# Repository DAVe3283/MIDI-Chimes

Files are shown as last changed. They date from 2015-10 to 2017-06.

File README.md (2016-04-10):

# MIDI-Chimes
Software &amp; notes from retrofitting some old chimes to MIDI control

Eventually, this will contain schematics, PCB layouts, data sheets, and source
code to make everything work. I will add things as I get to them.

## Project Details

TODO: writeup project details

## Firmware

The project uses several Teensy 3.2 microcontrollers. There is a master, which
handles MIDI and the user interface. The rest are slaves, which run 10 chimes
each.

The master and slaves communicate over I2C. The master talks to a touch screen
LCD over SPI.

### Libraries

I am using the following libraries:

* [i2c_t3][] - A superior I2C library that runs quite fast on the Teensy3.
* [ILI9341_t3][] - An optimized ILI9343 SPI LCD driver library for the Teensy3.
* [ILI9341_fonts][] - Additional fonts for ILI9341_t3.
* [Adafruit_STMPE610][] - STMPE610 SPI touch screen controller library.
* [Adafruit_FT6206][] - FT6206 I2C touch screen controller library.
* [SdFat][] - SD Card + FAT file system library.
* [IniFile][] - Arduino library to parse INI files.

Some minor changes are needed to make the libraries work together for this
project.

#### Adafruit_STMPE610

The line `#include <Wire.h>` needs changed to `#include <i2c_t3.h>` or it
conflicts with the i2c_t3 library.

#### SdFat

To work right, the SdFat library needs the following settings in SdFatConfig.h:

`#define SD_SPI_CONFIGURATION 1`

This uses the Arduino SPI.h library, which is really an optimized one for the
Teensy 3.1.

`#define ENABLE_SPI_TRANSACTION 1`

This enables SPI transactions, which makes using multiple devices on the SPI bus
much nicer.

I had some issues with SdFat-beta, but I might go back and make that work,
because it does some cool stuff.

#### IniFile

In IniFile.h, `#include <SD.h>` needs changed to `#include <SdFat.h>`.

Immediately below the includes, add the following so the inline code works with
this program:

```c++
extern SdFat sd;
#define SD sd
```

## Schematics

See the "PCB & Schematic" directory, and the [PCB.md](Notes/PCB.md) file.

## License

Content in each folder may be licensed differently. Overall, I strive to use the
Unlicense, but some portions may use external libraries preventing that. Those
portions will be licensed as necessary. Data sheets and the like are provided
for reference only, and are subject to all licenses/copyright specified within.

[Adafruit_FT6206]: https://github.com/adafruit/Adafruit_FT6206_Library
[Adafruit_STMPE610]: https://github.com/adafruit/Adafruit_STMPE610
[i2c_t3]: https://github.com/nox771/i2c_t3
[ILI9341_fonts]: https://github.com/PaulStoffregen/ILI9341_fonts
[ILI9341_t3]: https://github.com/PaulStoffregen/ILI9341_t3
[SdFat]: https://github.com/greiman/SdFat
[IniFile]: https://github.com/stevemarple/IniFile

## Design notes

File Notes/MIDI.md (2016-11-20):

# MIDI Messages

## Channels

The MIDI standard has 16 channels, theoretically for up to 16 different devices.
However, multiple devices can share a channel, so... ??

## Programs

MIDI programs are basically instruments. A Program Change message is sent to a
channel, and that channel is now supposed to be that instrument. Or that is what
seems expected in the real world.

## MIDI Keyboard Specific

I bought a Monoprice [606607][] 49-Key MIDI keyboard to use with the chimes.
I plan to take advantage of some of its features.

The keyboard uses rotary encoder A1 to set the program (instrument) and encoder
B2 to set the channel volume (Control Change for controler 0x07), 0-127.

### Analog Slider

There is an analog slider that I could use as an easier/quicker way to set the
volume on the chimes. I should make this an option in the GUI.

In the default config, it sends CC 147 (Master Volume), 0-127.

| Position | Raw Value  | Message |
| ---: | ---: | --- |
| 0% | 0 (0x00) | `F0 7F 7F 04 01 00 00 F7` |
| 25% |  32 (0x20) | `F0 7F 7F 04 01 00 20 F7` |
| 50% |  64 (0x40) | `F0 7F 7F 04 01 00 40 F7` |
| 75% |  96 (0x60) | `F0 7F 7F 04 01 00 60 F7` |
| 100% | 127 (0x7F) | `F0 7F 7F 04 01 00 7F F7` |

I think it might be good to honor this as well as the channel volume.

### Modulation Wheel

This is probably present on more keyboards than an analog slider, so I might
consider allowing this to control volume as well (as an option in the GUI).

The message is the standard modulation wheel (Control Change for controller
0x01), 0-127.

This should probably be off by default, because this would not be any kind of
expected behavior, and certainly wouldn't be intuitive.

# Our Behavior

Officially, we should make the user select a channel (1-16), and only listen to
that channel. Additionally, we would only play notes on that channel if a
program of 14 (0x0E, tubular bells) was selected.

However, we can't control/predict how MIDI files will be written. So the
official behavior might end up not playing certain songs at all, or requiring
the user to select the right channel.

So, we can do a couple things:

* Follow the spec
* Listen on all channels for just Tubular Bells
* Listen on one channel for all programs

The options above could be selected as a mode by the user.

## Follow the spec

This would behave as expected in a production / commercial environment. But I
really think this would cause a lot of MIDI files not to play back.

## Listen on all channels for just Tubular Bells

If we add an "All" to the channel selection, this could be a good option. It
follows the spec, unless the user says "ALL". And in that case, it is pretty
clear what will happen, IMO.

I would lean toward this option.

### Tech Details

I would probably need an array of bools for all 16 channels to track if they are
currently configured for Tubular Bells. Because some wanker might use multiple
channels of bells for some reason.

## Listen on one channel for all programs

Upside: This would cause MIDI files not designed for chimes to play.

Downside: This would cause MIDI files not designed for chimes to play.

This is probably a bad enough option it isn't worth implementing.

## Decision

I will follow the spec, but implement an "ALL" channel that listens for tubular
bells on all channels.

Internally, both the Teensy USB MIDI library and my library use channel 0 to
indicate ALL/ANY. So I have to add 1 to the channel as it comes in over the MIDI
port to match USB MIDI behavior.

# MIDI OUT / THRU

I will be using a single combined OUT/THRU port, with behavior selected in
software.

Officially, the MIDI OUT port is for data generated by the chimes. But chimes
don't really generate data.

I am thinking there should be a setting to control if MIDI files played by the
chimes send data to the MIDI OUT port or not.

I guess, fundamentally, I don't know what I want to do with this port yet.

[606607]:http://www.monoprice.com/product?p_id=606607

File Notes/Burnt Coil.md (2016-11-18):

# Burnt Coil Rebuild

One of the coils for the chime was overheated and damaged. It measured
approximately half the impedance of the normal coils, and was visibly burnt.

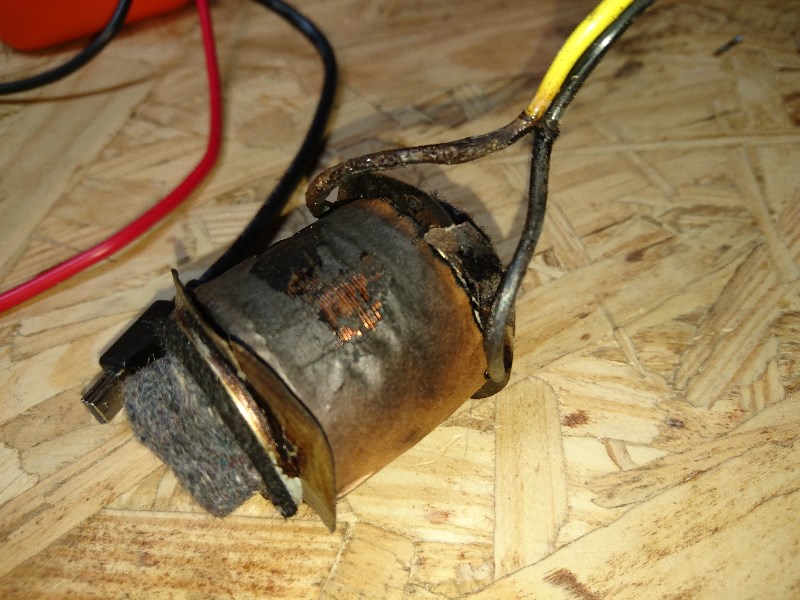
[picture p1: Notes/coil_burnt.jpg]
Picture of the burnt coil


The high current through this coil was causing problems for the transistor I
selected for the driver board, so I decided to re-wind the coil.

## Original Winding

To start, I removed the existing windings by hand. The first 5 layers were all
50 turns per layer, so I stopped counting turns and started counting layers. I
still periodically verified the layers were 50 turns, and they were throughout.

### Turns

Final result: **950 turns** (50 turns per layer, 19 layers)

It is technically possible I mis-counted layers, and it is actually 1000 turns
(20 layers), but I was careful, so I think it actually is 950 turns.

### Wire

Wire is 0.018" ± 0.0005" (indicated) based on my measurements with a cheap
Harbor Freight digital caliper. That puts it at a nominal 24 or 25 gauge.

Total wire length removed is approximately 250' (measured with a tape measure).

Calculating the expected resistance for 250' of 25 AWG wire yields 8.09 ohms,
which matches the other coils (8.0 ohms on my meter).

I think it is safe to say the coil uses **25 AWG** magnet wire.

## Core

The coil core was then exposed, and was measured.

The center section was not actually round, but narrowed in the center slightly.
The outer edges are 14.0 mm in diameter, and the center is 13.5 mm in diameter.

The winding section is 31 mm long, though the original winding didn't take the
whole area, but was centered on it. I was unable to get a good measurement of
the original winding width, but it appeared to be about 22-25 mm wide.

## New Winding

I ordered 25 AWG magnet wire, and used my lathe to re-wind the burnt coil with
new wire. I didn't have the proper paper for separating layers, so I used
standard multi-purpose copy paper soaked with insulating varnish. Not ideal, but
it worked.

I ended up winding the coil with more turns per layer and less layers than the
original. The rebuilt coil measures 7.2 ohms, so a little low, but way better
than the sub-4 ohm resistance from before.

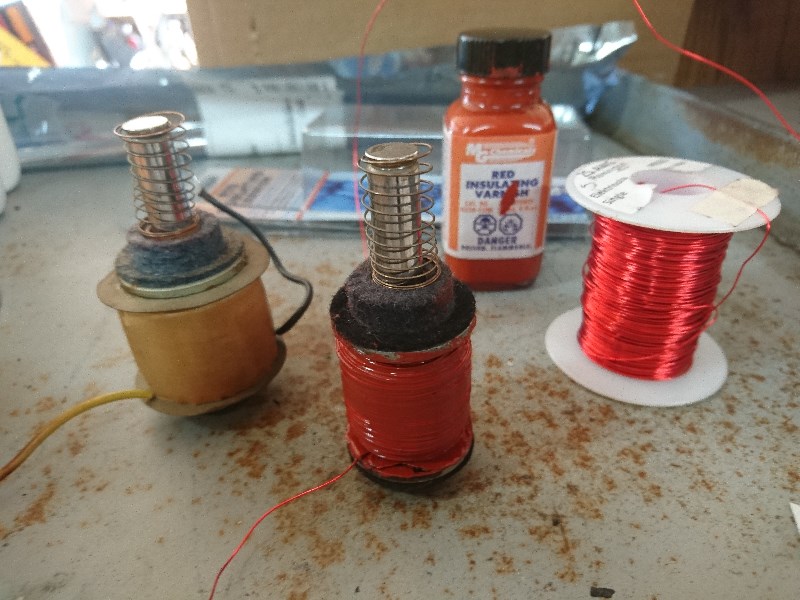
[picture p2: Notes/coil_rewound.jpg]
Picture of the rewound coil next to an original coil


The new coil tests out fine using a bench supply, and should be easy to
calibrate with the firmware to match the original coils.

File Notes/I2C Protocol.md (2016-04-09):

# I2C Protocol

This documents the protocol I am using for the I2C bus.

# Write (Master to Slave)

While I could get clever and allow multiple channels to be turned on and off per
message, there is no need for this. The I2C bus is substantially faster than the
incoming MIDI messages (per the spec, at least), so I can be lazy and just
handle one channel at a time.

Even more lazy, since the strike time for the chime is predetermined, and there
are no dampers on this setup, I don't even have to support a "note off" message
at all! So I don't.

## Note On Message

| Offset | Size | Type | Meaning |
|---|---|---|---|
| 0 | 1 | uint8_t  | Channel |
| 1 | 2 | uint16_t | PWM Duty Cycle |

### Channel

The channel (local to the current slave) is which activated/struck.

### PWM Duty Cycle

This is a 12-bit value (sent as 16-bits). Any value greater than 12 bits is
treated as 100% by the Teensy libraries.

I believe this is sent as little-endian, but it doesn't matter since both master
and slave use the same processor.

# Read (Master request from Slave)

When the master requests a read from the slave, the slave writes the following
packet back to the master.

## Status Packet

| Offset | Size | Type | Meaning |
| -----: | ---: | --- | --- |
| 0 | 1 | uint8_t  | Message Version |
| 1 | 1 | uint8_t  | PWM Bits |
| 2 | 1 | uint8_t  | Physical Channels (n) |
| 3 | 1 | uint8_t  | Connected Channels |
| 4 | 2 | uint16_t | Power Supply Voltage  |
| 6 |  n*1 | uint8_t  | Channel State |
| 6+n |  n*1 | uint8_t  | Strikes Remaining |
| 6+2n |  n*2 | uint16_t | Channel Voltage |

### Message Version

Currently set to 0, but this allows me to change things in the future in a
backwards-compatible way.

### PWM Bits

How many bits resolution the PWM is using on this slave. Currently 12, but could
change. The master should ensure all PWM duty cycle values are in this range.

### Physical Channels

How many physical channels this board has. Currently 10.

The message is scaled to the number of channels used.

### Connected Channels

How many of the physical channels appear to be connected to chime coils.

This is there because I have 25 chimes, so the last slave board will only have
5 connected channels.

### Power Supply Voltage

The slave board's best guess at power supply voltage setpoint, measured during
startup.

### Channel State

This is an enum value that indicates the current state of each channel.
Currently:

| Value | Meaning |
| ----- | --- |
| 0 | Working normally |
| 1 | Disconnected (no coil detected) |
| 2 | Transistor failed to short circuit |
| 3 | Transistor failed to open circuit  |

The channel disconnected status is so the master can verify the expected number
(and location) of coils are connected. If something isn't right, it should
display a message to the user, and ask them to verify the connections.

If a channel is failed to short circuit, the main power supply should be turned
off to prevent damage to the coil attached to that channel. The slave will
attempt to do this on its own, but the master should turn off the main supply
itself, just to be safe. The master should display a message to the user, so
they know what happened.

If a channel is failed to open circuit, it is safe to keep using the channel and
to leave the master supply on, but that channel may not work. The master should
display a message to the user so they know what happened.

### Strikes Remaining

A counter of how many more times we can strike this chime before the coil is
considered overheated. If this value is 0, the channel is overheated and will
ignore strike commands to protect the coil.

As time passes (and the coil cools), this value will increase, allowing the
channel to be used again.

This is purely informational, as the slave manages the thermals. However, it
might be fun to have a live display of the strikes remaining values.

### Channel Voltage

This is the last measured voltage of the given channel with the transistor off
(not striking the chime). It is measured once at startup, and again every time
a chime is finished striking.

This is purely informational, but might be fun to have a live display on the
master of all the channel voltages.

# Startup Process

The startup process is a bit more complex, and might stretch the spec a bit...

The slaves power up and start listening on the I2C General Call Address (0x00).
All slaves listen simultaneously, since the bus is shared.

## Commands

The master uses 2 byte messages during startup. The 1st byte is a command, and
the 2nd byte is the value. The meaning of the value is described below.

| Command | Value |
|---|---|
| 0x00 Set Address | Address to use if/when ADDR_LATCH goes high |
| 0x01 Set ADDR_LATCH | Set the output ADDR_LATCH pin to this value |
| 0x02 Startup Complete | Value is currently ignored |

### 0x00 Set Address

When this command is received, all slaves prepare to switch to this address.
But only when ADDR_LATCH_IN goes high does it take effect, so only one slave
will actually get assigned to the address.

### 0x01 Set ADDR_LATCH

Since only the first slave is connected to the master directly, the master has
to request downstream slaves set their ADDR_LATCH_OUT, so that the next slave in
line latches the last address sent.

### 0x02 Startup Compete

When the master is done with a slave, it sends this, telling the slave to begin
normal operation. The value sent with this command is currently ignored.

## Fun Extras

It would be interesting to test and see if the R_BE (Base-Emitter resistance)
across the transistors is fairly consistent. From the data sheet, it looks to be
0.45-0.56 ohms depending on current flow. My testing shows it vary from 120 ohms
at 5mA then dropping quickly under 1 ohm by 1 A, and down to ~0.45 ohms at ~2.5
amps.

Perhaps instead, I could connect some various resistive (or inductive) loads and
just make a calibration curve of feedback voltage (at 100% PWM) vs. current, if
the transistors are consistent enough. Might be fun to have each coil's current
consumption (and resistance, since we have the power supply voltage) show up in
a diagnostics screen on the master.

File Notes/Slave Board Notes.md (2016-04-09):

Notes about the slave board.

Voltage measured with transistor on 100%:

| Current (mA) | Voltage |  R_BE |
| ---: | --- | ----: |
| 5 | 0.6 | 120.0 |
| 1000 | 0.8 | 0.8 |
| 2000 | 0.9 |  0.45 |
| Actual Coils | 1.1 | ~0.44 |

So any voltage over 0.5V at boot means something is connected.
I should probably consider anything under 1.5V (and < 50% ps_setpoint) shorted at startup.

Or, since the chimes will draw ~2A, simply subtract 0.9V from the measured
voltage, and use that for the percentage calculations to verify operation?

Perhaps some testing with the real chimes is in order...

Measured values from my chimes.
Ideal values calced with
    ideal_voltage = ps_setpoint - ((ps_setpoint - transistor_Vce_drop) * set_dc[channel])
    ps_setpoint = 19.13
    transistor_Vce_drop = 1.1

| PWM DC | Measured | Ideal | Error |
| -----: | --- | ----- | ----: |
| 0% | 19.13 | 19.13 |  0.0% |
| 10% | 17.76 | 17.33 | -2.3% |
| 20% | | 15.52 | |
| 30% | 14.07 | 13.72 | -1.8% |
| 40% | 12.18 | 11.92 | -1.4% |
| 50% | 10.31 | 10.12 | -1.0% |
| 60% | 8.38 |  8.31 | -0.4% |
| 70% | 6.51 |  6.51 |  0.0% |
| 80% | 4.61 |  4.71 |  0.5% |
| 90% | 2.73 |  2.90 |  0.9% |
| 100% | 1.10 | 1.1 |  0.0% |

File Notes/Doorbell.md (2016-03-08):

I want the chimes to work as a doorbell as well as MIDI chimes. Why? Why not?

To make this happen, I bought a doorbell (GE 19247) for $14 or so.

# GE 19247

This sucker is surprisingly well designed. The PCB appears to be one layer
(though it has screen-printing on both sides), with the CPU inserted vertically
on a card. Impressively well laid out, IMO.

Furthermore, it appears the speaker output is isolated from ground. This is the
correct way to do things (I am impressed, especially at this price point), but
sadly, that means simply snooping a speaker pin won't work.

## EEPROM

There is a FM24C02C 256x8 bit EEPROM attached to the CPU. When the doorbell
button is pressed, there is some I/O traffic to the EEPROM. Here is one exchange
I captured.

| Address |  R/W  | Value |
|---|---|---|
| 0x13 | Read  | 0x0A  |
| 0x01 | Read  | 0x26  |
| 0x02 | Read  | 0x87  |
| 0x03 | Read  | 0x90  |
| 0x14 | Read  | 0x0A  |
| 0x04 | Read  | 0x79  |
| 0x05 | Read  | 0xA5  |
| 0x06 | Read  | 0xD0  |
| 0x0A | Read  | 0x01  |
| 0x0A | Write | 0x01  |

I have no idea what it is doing with that data (or why it re-writes 0x0A from 1
to 1), but it doesn't matter for what we are doing.

## A trick!

Since we can't read the speaker output (floating ground), we need _some_ way to
tell the doorbell button was pressed. Well, we can watch SCL (or SDA) for a
high-to-low transition. That indicates the start of some I2C traffic, and
therefore, a button press!

## Measurements

The SCL and SDA lines appear to be pulled up to 2.7V, and the CPU itself runs
on 2.9V. 2.7V should be sufficiently high to count as logic high on the Teensy,
which runs at 3.3V.

The I2C bus is clocked at approximately 5.6 kHz, with occasional long pauses
mid-transaction. Given how slow it is, I doubt the wire running to the Teensy
will cause any bus corruption.

# TODO

I need to solder a wire to the SCL line, and hook it to the Teensy to verify I
can reliably detect button presses. I should also leave it running for a long
time period to count bus events, and make sure there is no random idle bus
traffic that would cause the doorbell to go off randomly.

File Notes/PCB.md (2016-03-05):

# Data Connector Pinout

This is the connector between the master and slave devices.

| Pin |  Description  |
| --- | --- |
| 1 | Ground |
| 2 | +5V_SB |
| 3 | I2C SCL |
| 4 | I2C SDA |
| 5 | Address Latch |
| 6 | PS_EN |

+5V_SB is 5V standby power from the PSU.
PS_EN is the power supply enable line.
Address latch is used to auto-assign I2C addresses on startup (future use).

If I did this right, no magic smoke should escape if (when) someone plugs this
connector in backwards. Off-by-one... not so much.

# Transistor Feedback Voltage

I am using a 160k / 10k resistor divider, with a 1 uF capacitor in parallel with
the 10k resistor. Using the Teensy3's internal 1.2V precision reference, I can
read a transistor voltage of 0 to 20.4 volts. The capacitor filters out the PWM
frequency, letting me be extremely lazy with my firmware when checking how
things are working.

# Master

## Power Supply Connector

This is the pinout of the connector on the high voltage power supply.

Note how the power supply datasheet counts terminal numbers! It might not be
what you expect. For consistency, I use the same numbering as the datasheet.

| Pin | Description |
|-----|---|
| 1 | RC+ |
| 2 | RC- |
| 3 | AUX (5V_SB) |
| 4 | AUX_GND |
| 5 | +S |
| 6 | -S |

### RC

The RC+ and RC- pins are for Remote Control of the power supply. Shorting RC+ to
RC- will turn off the power supply. It also appears that RC- is internally tied
to AUX_GND, but I probably should explicitly do that on the PCB to be safe.

### AUX

This is a 5V standby power supply, limited to 300 mA. I think we come in under
that, but it bears testing. If not, I might have to get creative...

### +/-S

This is a sense line to compensate for voltage droop at the load. We don't care,
so these should be left unconnected. Probably best not to put wires in the
header, so stray EMI doesn't get picked up.

## I2C Bus

I need external pullup resistors on the I2C bus, as the internal Teensy ones
don't work all that well. For high speed, I probably want 1.5k or so.

## Legacy MIDI Ports

I am going to support the legacy DIN MIDI jacks. MIDI uses a current loop and
opto-isolator (optocoupler) to avoid ground loops. I will be using the 6N138.

I think I can use the MAB5SH part in Eagle as the footprint for the MIDI conenctor.
    Yeah, I think we're good. But just in case: http://www.newark.com/hirschmann/mab-5-sh/din-audio-video-connector-socket/dp/61T4646

I need to use a protection diode on the MIDI In port to protect the optocoupler
from exceeding its breakdown voltage (5V max). I could use the diode I use to
absorb flyback from the coils. Massive overkill, but simplifies the BoM. A small
surface mount part might be easier to lay out, though.

### Simple Option

I need some sort of output transistor for the MIDI out/through circuit.
Worst case, a shorted cable could cause a load of up to 23 mA (5 V / 220 ohms)
when pulling MIDI_OUT to ground, but the Teensy can only handle 9 mA per pin.

Plus, a faulty/malicious device could actually put more than 5V on Pin 5. A
transistor with sufficient ratings solves all this.

#### Overkill option

Because this is a chance for me to have too much fun with design and learn some
things, I could isolate the MIDI out as well. I would need an opto-isolator, and
an isolated power supply to provide the 5V for the current loop and to run the
optocoupler.

I will order a REE-0505S from Mouser and see if it works well enough. If not, I
will try a MEV1S0505SC, but this would need a footprint designed for Eagle.
(Actually, I need to verify the generic DC-DC footprint works on the REE...)

If that all works, I could route out an isolation gap in the PCB, and do all the
high-voltage design. Of which I currently know nearly nothing. But once I learn,
I would have a MIDI input/output stage with > 1000V isolation! heh

## Misc

http://www.mouser.com/ProductDetail/Molex/15-91-2140/?qs=sGAEpiMZZMttdt6ek4ZYDGcRuHgvKenX
    This is for the pads on the back of the Teensy.

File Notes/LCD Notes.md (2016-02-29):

Notes about the LCD screen.

# Connection / Pins

The display pins are numbered like an Arduino UNO.

| Circuit | Teensy | Arduino |
| ---  | -----: | ---: |
| LCD Reset | 7 | RESET |
| SPI Touch CS  | 8 | 8 |
| I2C Touch SCL | 19 | A5/SCL  |
| I2C Touch SDA | 18 | A4/SDA  |
| LCD DC | 9 | 9 |
| LCD CS | 10 | 10 |
| SPI MOSI | 11 | 11 |
| SPI MISO | 12 | 12 |
| SPI SCK | 14 | 13 |
| MicorSD CS | 15 | 4 |
| LED Backlight | 3 | 3 |

CS = chip select
DC = data/command select, appears non standard, used for display
I2C: Use the pins on the same side as the SPI bus of the display board. Arduino exposes these pins in two places, and only one pair works.

# Backlight

The backlight intensity can be controlled by PWM-ing the backlight pin to switch
the LEDs on and off.

I tried a 16-bit PWM @ 549 Hz and could see no noticable flicker. I think that
16 bits is serious overkill. Even 8 bits might be overkill.

| PWM % DC | Percieved Brightness |
|---|---|
| 0% (Off) | Can't see anything |
| 1/65535  | Can't see anything |
| 1% | Very dim, almost unusable |
| 5% | Usable in soft indoor light |
| 10% | About 25% full brightness |
| 30% | About 50% |
| 50% | About 75% |
| 90% | About 98% |

If the backlight is turned completely off, you can't see _anything_, even by
shining a flashlight on the screen. For all intents and purposes, the screen is
off. We probably want to avoid this.

For a standby/eco mode (power supply off), something in the 1% - 5% range is
probably good.

For an "unattended" mode (chimes active but no display interaction for some
time), something in the 30-50% rand is probably good.

It would be cool to have it smoothly ramp the brightness up and down as the
chimes transition between various power saving modes. Make the transition quick
enough to not get in the way of user operation, but slow enough to look good.
That probably means in the 100 - 500 ms range to get brighter on interaction.
We could fade out much more slowly (1-5 seconds?) though.

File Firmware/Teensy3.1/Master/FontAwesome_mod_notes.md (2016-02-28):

# FontAwesome_mod

What things are in my custom FontAwesome mod...

## Battery

0 = Battery 100%
1 = Battery 75%
2 = Battery 50%
3 = Battery 25%
4 = Battery 0%

## Hourglass

5 = Hourglass (Outline)
6 = Hourglass Top (start)
7 = Hourglass Both (in progress)
8 = Hourglass Bottom (end)
9 = Hourglass (Solid)

## Overflow Menus

- = Vertical Overflow
, = Horizontal Overflow

## Home

x = Home / House

## Settings

s = Single Gear
t = 3 Gears
u = Sliders
v = Bars
w = Wrench
| = Gauge
. = Slider Off
/ = Slider On

## Power

@ = Power Plug (AC power)
A = Power Button
B = Lightning Bolt (charging)
C = Leaf (eco or standby)

## Media Playback

D = Music Note Symbol

E = Volume Mute
F = Volume Down
G = Volume Up

H = Shuffle

I = |<  Step Backward
J = |<< Fast Backward
K = <<  Backward
L =     Play
M =     Pause
N =     Stop
O = >>  Forward
P = >>| Fast Forward
Q = >|  Step Forward
R =     Eject

## Info Symbols

S = i   Information (in circle)
T = !   Exclamation (in circle)
U = !   Exclamation (in triangle)
V = ?   Question (in circle)

## Bells

W = No Bell (solid)
X = No Bell (outline)
Y = Bell (solid)
Z = Bell (outline)

## Stars

< = Empty Star (outline)
; = Half Star
: = Full Star (solid)

## Locks

> = Lock (closed / locked)
? = Lock (open / unlocked)

## Eyes

\ = Eye
[ = No Eye (slash through eye)

## File Symbols

] = Level Up
^ = Level Down
_ = Folder, Closed (solid)
` = Folder, Closed (outline)
a = Folder, Open (solid)
b = Folder, Open (outline)
c = File, Generic (solid)
d = File, Generic (outline)
e = File, Text (solid)
f = File, Text (outline)
g = File, PDF (outline)
h = File, "W" (outline)
j = File, "P" (outline)
k = File, Picture / Image (outline)
l = File, Archive / ZIP (outline)
m = File, Sound / Music (outline)
n = File, Video / Movie (outline)
o = File, Code / Config (outline)

p = Two Files / Copy (outline)
q = Floppy / Save (outline)

## Misc

) = Shield
* = Bug
+ = Motorcycle
= = Trash Can

y = USB Logo
z = Bluetooth (in shape)
{ = Bluetooth (just the logo)

} = Fire / Flame
~ = Fire Extinguisher

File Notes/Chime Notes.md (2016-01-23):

# Chime Notes

This maps the chime notes to MIDI notes.

The keyboard is laid out like such:

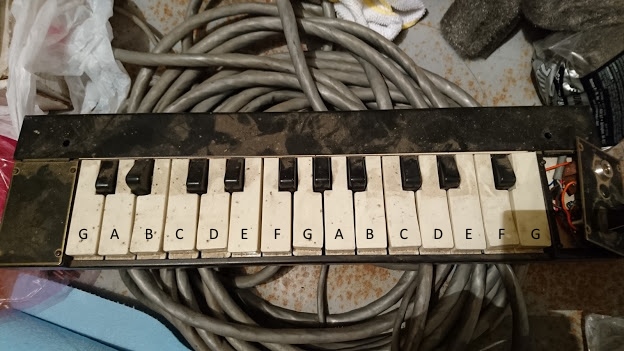
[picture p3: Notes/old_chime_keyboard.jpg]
Picture of the original keyboard for the chimes


```
 G# A#   C# D#   F# G# A#   C# D#   F#
G  A  B C  D  E F  G  A  B C  D  E F  G
```

I am not sure which octaves that covers, though. I need to measure the frequency
of the chimes to be sure.

For now, I am going to randomly assume it is G3 (MIDI 55) through G5 (MIDI 79),
since that seems to match a lot of MIDI files I found online for chimes.

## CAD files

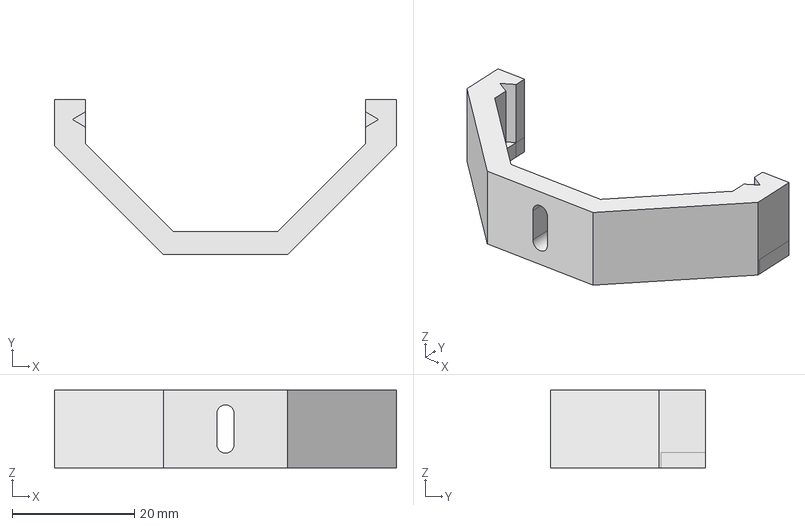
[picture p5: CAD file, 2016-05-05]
Mounting/Slave Board Clip.FCStd
55.9 x 25.4 x 12.7 mm

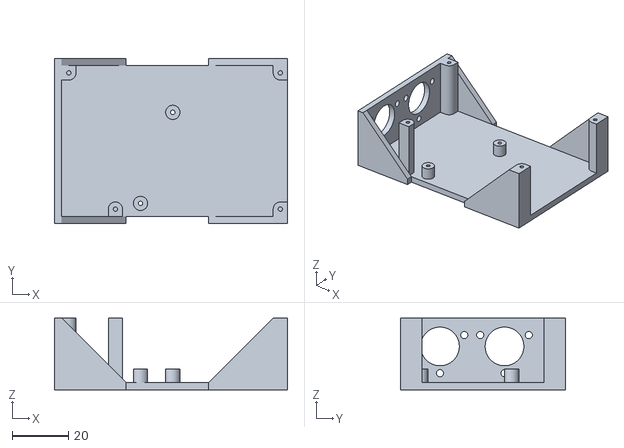
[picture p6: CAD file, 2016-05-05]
Mounting/Master Board Mount with Pilot Holes.stl
82.6 x 58.4 x 25.4

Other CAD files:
Mounting/Master Board Mount.FCStd
Mounting/Master Board Mount.stl
Mounting/Slave Board Clip.stl

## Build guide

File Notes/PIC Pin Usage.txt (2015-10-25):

Looks like I can run 3 chimes per PIC without issue. The 4th PWM channel
conflicts with I2C and SPI, so I wouldn't be able to talk to the PIC.

Pin		Function
===		========
Pin 1	Vdd (+5V, ICSP)
Pin 2	RA5 (PS_Enable)
Pin 3	AN3
Pin 4	/MCLR (ICSP)
Pin 5	PWM 1 (Transistor 1)
Pin 6	RC4 (Address_Latch)
Pin 7	PWM 2 (Transistor 2)
Pin 8	RC2 (LED)
Pin 9	I2C (SDA)
Pin 10	I2C (SCL)
Pin 11	PWM 3 (Transistor 3)
Pin 12	AN1, ICSPCLK
Pin 13	AN0, ICSPDAT
Pin 14	Vss (Ground, ICSP)

Note: I can swap pins 2, 6, & 8 as needed, since they are just digital I/O.

---==[Analog Pins]==---
Analog pins are used to measure transistor collector voltage (through a 
voltage divider).
This lets me see if they failed in the on state. If I get ambitious, I can also
see if they are turning on correctly. As appropriate, I will force the power
supply off (to prevent burning out a coil and/or a fire), and/or send a fault
message back to the Teensy.

---==[PS_Enable]==---
This pin is tied to the watchdog timer driven by the Teensy. When toggling, the
watchdog turns on the power supply. If there is a fault, the PIC will force this
to ground, in turn forcing the power supply off. The Teensy can detect this, and
will query the I2C bus to find which module faulted. (I might also query fault
status periodically from the Teensy.)

---==[Address_Latch]==---
This pin is used to indicate the I2C address previously broadcast on the bus
should be the new I2C address of this chip. It is used to allow dynamic address
selection of a string of driver boards, enabling easy replacement.
The pin is tied to the LED pin of the previous board (or the master Teensy). If
the chip is in startup mode, it latches the address. Once it has latched an
address, it ignores this input for the duration of operation.

---==[LED]==---
The LED will be illuminated if a fault is detected, allowing the driver board to
easily be identified for replacement. The Teensy will also display which board
failed, but this makes things even more clear.
This pin is also used to latch the address into the next chip during startup.

---==[ICSP]==---
In Circuit Serial Programming (ICSP) require re-use of the AN0-1 pins. Since
they are on a voltage divider, this should still work, even with the power
supply on. If the power supply is off or disconnected, there will be no problem.

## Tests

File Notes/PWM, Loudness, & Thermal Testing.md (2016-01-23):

# PWM Setting Tests

The PIC16F1503 has limited PWM frequencies when targeting 9-10 bit resolution.

| Frequency (Hz) | Resolution | CPU Clock | Transistor Temp | Coil Whine? |
| ---: | ---: | ---: | :--- | :--- |
| 1,953 | 10-bit | 8 MHz | <Untested> | <Untested> |
| 4,883 | 10-bit | 20 MHz | Excellent | Yes, within ~1' |
| 7,813 | 10-bit | 8 MHz | Excellent | Barely, within ~6" |
| 9,766 | 9-bit | 20 MHz | Good | Barely, within ~4" |
| 15,625 | 9-bit | 8 MHz | <Untested> | <Untested> |
| 19,531 | 10-bit | 20 MHz | Needs heatsink  | None |

All _tested_ settings functioned just fine.

## Summary

It looks like 7,813 Hz is about ideal. Transistor runs really cold (probably
doesn't need a heatsink at all!); coil whine should be unnoticeable once covers
are in place, even standing close.  If coil whine is an issue, moving to
9,766 Hz would work, but heatsinks might be a good idea at that frequency.

A strike time of 85 to 100 ms is ideal for sound. The longer the strike, the
harder it is to keep things cool. 90 is a good compromise.

A settling time of 150 ms seems to sufficient, though going 160 ms with a 90 ms
strike time leads to a nice clean 4 strikes per second. However, this rate
_WILL_ require overall thermal management over a rolling 60-second (or so)
window to protect the coil.

## Using a Teensy instead of PIC

Since we will now be using a Teensy instead of a PIC to PWM the coils, we can
improve the PWM resolution _and_ frequency at the same time.

On the Teensy, based on [these specs](https://www.pjrc.com/teensy/td_pulse.html),
it looks like our best bet is 12-bit PWM (0 - 4095) at 8,789.062 Hz with a 72
MHz CPU clock.

# Thermals

During testing, it quickly became apparent that the part most likely to have
thermal issues is the coil itself. Repeated striking of the chime caused the
coils to quickly heat up.

To manage this, I attempted to optimize strike time. Details are in the sections
below.

Also of concern is settling time (how long the striker takes to return to its
rest position and stop bouncing).

Testing indicates that 350 ms is the upper limit of a reasonable value, and 150
ms is the lower limit. Below 150 ms, the striker doesn't fully settle against
the stop, and begins to affect the strike volume and timing.

## Overall Duty Cycle

The coils do take some time to actually heat up (> 60 seconds). Overall, I
should enfoce a limit on the total on-time (or even number of strikes) in a
rolling 60-second window.

## Thermal Throttling

To avoid interfering with sections of music that rapidly strike the same note,
a rolling 60-second window with a 60 strike limit seems prudent. Every second,
decrement the strike counter, and increment it with every strike. If it ever
reaches 60 (or whatever limit is reasonable), deny the strike, and flag a
thermal overload for the next I2C report. This will allow the Teensy to display
a thermal warning, and which chime is overheated. Perhaps maintain the flag
until the counter reaches all the way to 0? Or until cleared by the Teensy?

# Strike Time Tests

| Strike Time (ms) | Minimum PWM DC | Actual On Time (ms) |
| ---: | ---: | ---: |
| 45 | 70% | 31.5 |
| 55 | 65% | 35.8 |
| 65 | 60% | 39.0 |
| 85 | 55% | 46.8 |
| 120 | 50% | 60.0 |

The faster the strike time, the harder it is to control volume. See the volume
tests below.

## Duty Cycle

Given a conservative 350 ms settling time, maximum duty cycle (assuming
back-to-back striking of the chime) can be calculated.

| Strike Time (ms) | Max Duty Cycle (%) |
| ---: | ---: |
| 45 | 11.4 |
| 50 | 12.5 |
| 55 | 13.6 |
| 60 | 14.6 |
| 65 | 15.7 |
| 70 | 16.7 |
| 75 | 17.6 |
| 80 | 18.6 |
| 85 | 19.5 |
| 90 | 20.5 |
| 100 | 22.2 |
| 125 | 26.3 |

# Chime Volume

I decided to measure chime volume for a given strike time and PWM DC %.
These are taken at about 1 meter with my Nexus 5. Or, in other words, are only
slightly better than made up numbers.

It turns out that above ~70 dB, the Nexus highly compresses the value. Most of
the measurements indicate that 90% and 100% PWM DC are the almost the same
volume, but that is not the case by far. So take these tables with a grain of
salt.

If a PWM value isn't listed, that is because the striker doesn't make contact
with the chime for a strike time that small combined with a PWM DC that small.

## 65 ms Strike Time

| PWM DC |  SPL  |
| -----: | ----: |
| 60% | 57 dB |
| 65% | 62 dB |
| 70% | 66 dB |
| 75% | 68 dB |
| 80% | 71 dB |
| 85% | 74 dB |
| 90% | 75 dB |
| 95% | 76 dB |
| 100% | 78 dB |

## 85 ms Strike Time

| PWM DC |  SPL  |
| -----: | ----: |
| 55% | 55 dB |
| 60% | 58 dB |
| 65% | 62 dB |
| 70% | 66 dB |
| 75% | 67 dB |
| 80% | 70 dB |
| 85% | 73 dB |
| 90% | 74 dB |
| 95% | 76 dB |
| 100% | 76 dB |

## 100 ms Strike Time

| PWM DC |  SPL  |
| -----: | ----: |
| 55% | 52 dB |
| 60% | 60 dB |
| 65% | 63 dB |
| 70% | 67 dB |
| 75% | 70 dB |
| 80% | 72 dB |
| 85% | 73 dB |
| 90% | 76 dB |
| 95% | 77 dB |
| 100% | 78 dB |

## Result Summary

The data is not as conclusive as I would like. I need a real SPL meter, with
peak hold.

Going by ear, it seems that 85-100 ms strike times yield identical outputs, so
that is a good range to stick in. Hence, why I picked a 90 ms strike time above.

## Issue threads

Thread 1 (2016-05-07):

Fix slave allowed error calc

DAVe3283, 2016-05-07:
The current method of calculating the allowed error on each slave board is based on how many chimes that particular slave is currently striking. This was done to work around an issue where the voltage would drop as the number of chimes struck at once went up, but it turns out I was just exceeding the rating of the power supply. Plus, they have no way of knowing how many chimes the other slaves (of which they also don't know) are striking, so this method is fundamentally flawed.

The master should control how many chimes can be struck simultaneously, and the slaves should just have a reasonable error limit (e.g. 2-5%). If a measurement is out of range, it is probably a good idea to shut down the power supply, because something _is_ wrong. I just thought it wasn't.

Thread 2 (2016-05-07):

Limit simultaneous chime strikes

DAVe3283, 2016-05-07:
The master board should limit the total strikes that happen simultaneously, to avoid exceeding the limits of the power supply.

Ideally, this limit should be read off the settings file on the SD card, but being hard coded is probably acceptable. Someone building a version of these with a different power supply would probably be capable of modifying and compiling the master firmware.

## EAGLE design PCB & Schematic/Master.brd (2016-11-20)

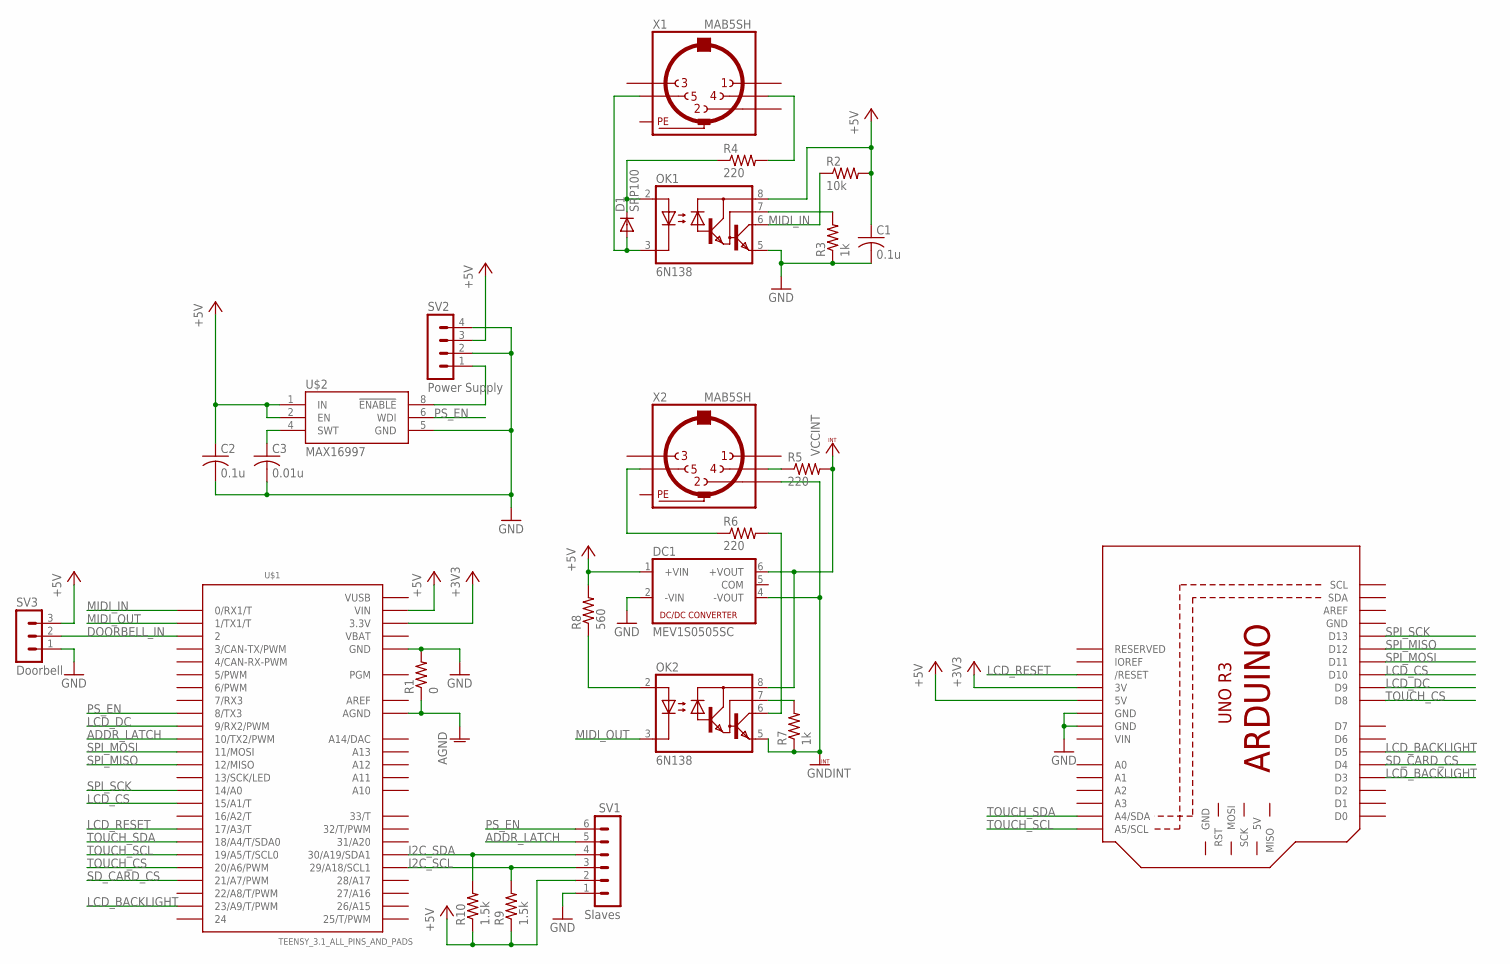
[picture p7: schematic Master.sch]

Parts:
C1, C2: 0.1u; C0805
C3: 0.01u; C0805
D1: SRP100; DO41-10
DC1: MEV1S0505SC; NMA
M1: ARDUINO_R3_ICSP_NODIM; ARDUINOR3_ICSP_NODIM
OK1, OK2: 6N138; DIL08
R1: 0; R0805
R2: 10k; R0805
R3, R7: 1k; R0805
R4, R5, R6: 220; R0805
R8: 560; R0805
R9, R10: 1.5k; R0805
SV1: Slaves; MA06-1
SV2: Power Supply; MA04-1
SV3: Doorbell; MA03-1
U$1: TEENSY_3.1_ALL_PINS_AND_PADS; TEENSY3_ALL_PINS_&_PADS
U$2: MAX16997; UMAX-U8-1
X1, X2: MAB5SH

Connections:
+3V3: M1.3V, U$1.3.3V, U$1.3.3V1 (3.3V), U$1.3.3V2 (3.3V)
+5V: C1.1, C2.1, DC1.1 (+VIN), M1.5V, OK1.8 (VCC), R2.2, R8.2, R9.1, R10.1, SV1.2, SV2.3, SV3.3, U$1.VIN, U$2.1 (IN), U$2.2 (EN)
ADDR_LATCH: SV1.5, U$1.10 (10/TX2/PWM)
AGND: R1.1, U$1.AGND
AREF: U$1.AREF
DOORBELL_IN: SV3.2, U$1.2
GND: C1.2, C2.2, C3.2, DC1.2 (-VIN), M1.GND, M1.GND@1 (GND), M1.GND@3 (GND), OK1.5 (GND), R1.2, R3.1, SV1.1, SV2.2, SV2.4, SV3.1, U$1.GND, U$1.GND1 (GND), U$1.GND2 (GND), U$2.5 (GND)
GNDINT: DC1.4 (-VOUT), OK2.5 (GND), R7.1, X2.2
I2C_SCL: R9.2, SV1.3, U$1.29 (29/A18/SCL1)
I2C_SDA: R10.2, SV1.4, U$1.30 (30/A19/SDA1)
LCD_BACKLIGHT: M1.D3, M1.D5, U$1.23/A9 (23/A9/T/PWM)
LCD_CS: M1.D10, U$1.15/A1 (15/A1/T)
LCD_DC: M1.D9, U$1.9 (9/RX2/PWM)
LCD_RESET: M1.RESET (/RESET), U$1.17/A3 (17/A3/T)
MIDI_IN: OK1.6 (VO), R2.1, U$1.0 (0/RX1/T)
MIDI_OUT: OK2.3 (C), U$1.1 (1/TX1/T)
unnamed: R6.1, X2.5
unnamed: OK1.7 (VB), R3.2
unnamed: D1.C, OK1.2 (A), R4.1
unnamed: R4.2, X1.4
unnamed: D1.A, OK1.3 (C), X1.5
unnamed: OK2.6 (VO), R6.2
unnamed: R5.1, X2.4
unnamed: C3.1, U$2.4 (SWT)
unnamed: OK2.2 (A), R8.1
unnamed: OK2.7 (VB), R7.2
unnamed: SV2.1, U$2.8 (!ENABLE)
PE: X1.PE, X1.PE@ (PE), X2.PE, X2.PE@ (PE)
PS_EN: SV1.6, U$1.8 (8/TX3), U$2.6 (WDI)
SD_CARD_CS: M1.D4, U$1.21/A7 (21/A7/PWM)
SPI_MISO: M1.D12, U$1.12 (12/MISO)
SPI_MOSI: M1.D11, U$1.11 (11/MOSI)
SPI_SCK: M1.D13, U$1.14/A0
TOUCH_CS: M1.D8, U$1.20/A6 (20/A6/PWM)
TOUCH_SCL: M1.A5 (A5/SCL), U$1.19/A5 (19/A5/T/SCL0)
TOUCH_SDA: M1.A4 (A4/SDA), U$1.18/A4 (18/A4/T/SDA0)
VBAT: U$1.VBAT
VCCINT: DC1.6 (+VOUT), OK2.8 (VCC), R5.2
VIN: M1.VIN
VUSB: U$1.VUSB

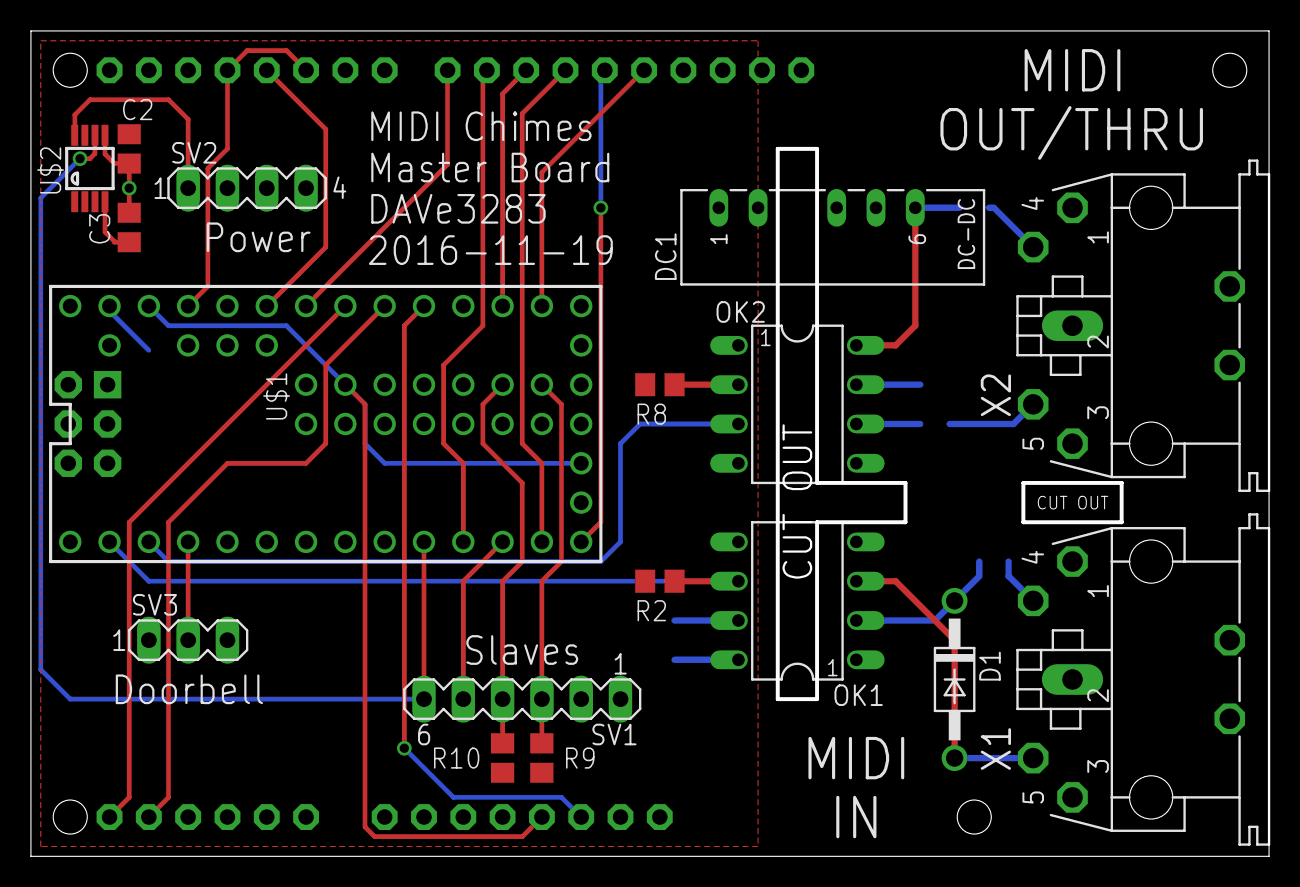
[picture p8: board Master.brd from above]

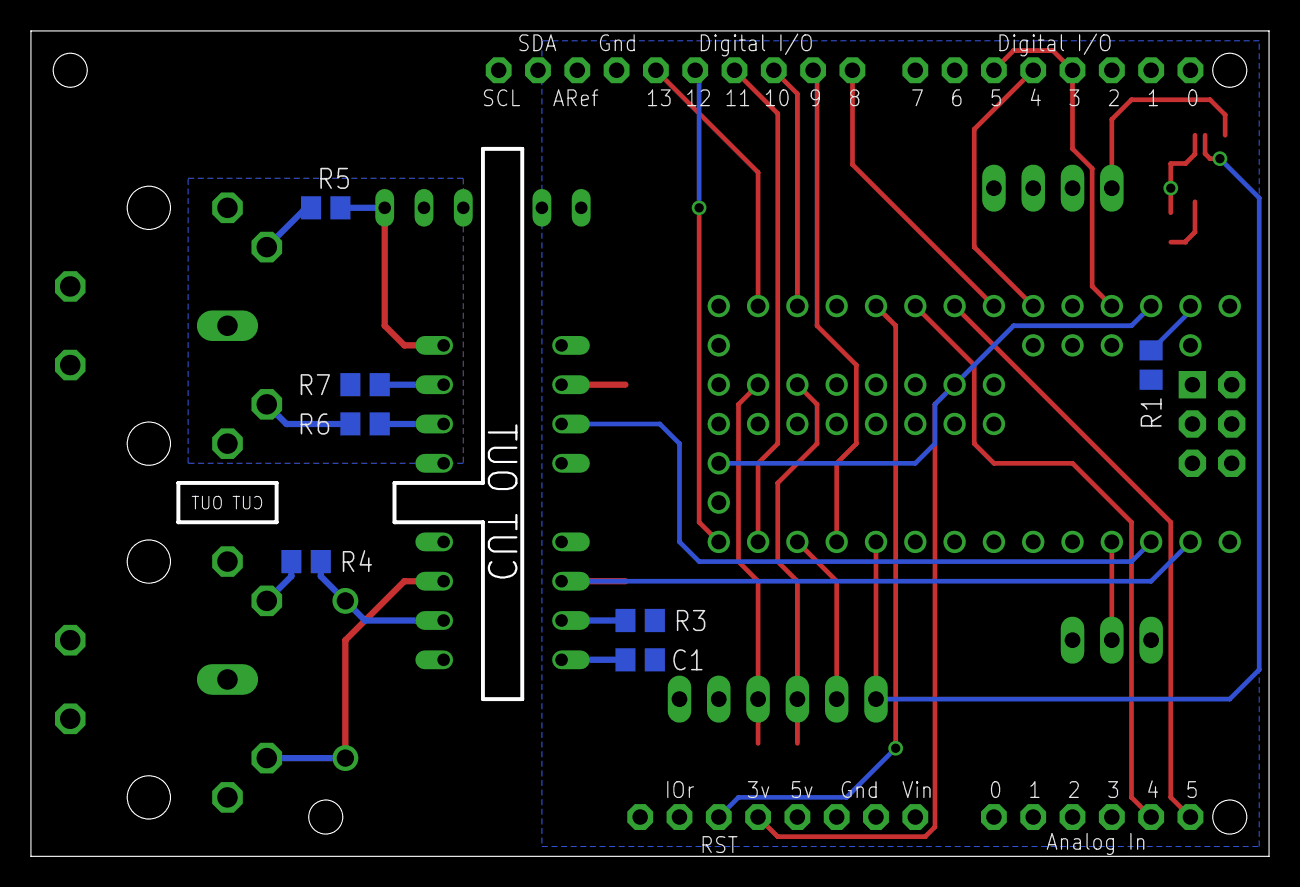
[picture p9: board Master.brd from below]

Board: 2 copper layers, 80.0 x 53.3 mm, 25 parts (8 on the bottom side), 36 nets.

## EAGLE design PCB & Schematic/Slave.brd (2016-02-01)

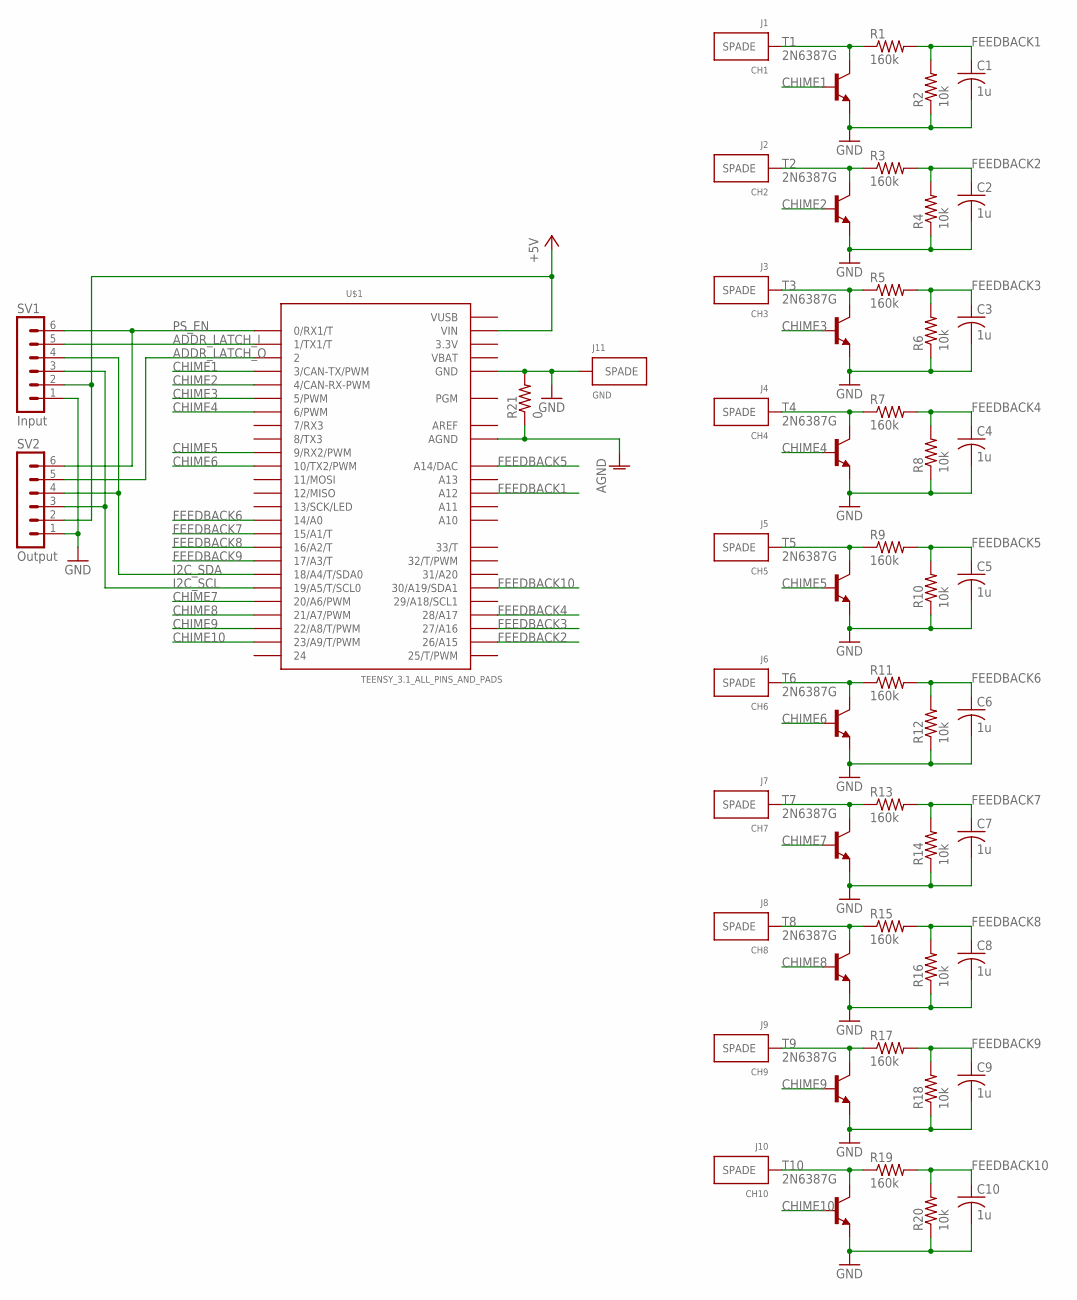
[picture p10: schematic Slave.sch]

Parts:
C1, C2, C3, C4, C5, C6, C7, C8, C9, C10: 1u; C0805
J1: CH1; 19705-4001
J2: CH2; 19705-4001
J3: CH3; 19705-4001
J4: CH4; 19705-4001
J5: CH5; 19705-4001
J6: CH6; 19705-4001
J7: CH7; 19705-4001
J8: CH8; 19705-4001
J9: CH9; 19705-4001
J10: CH10; 19705-4001
J11: GND; 19705-4001
R1, R3, R5, R7, R9, R11, R13, R15, R17, R19: 160k; R0805
R2, R4, R6, R8, R10, R12, R14, R16, R18, R20: 10k; R0805
R21: 0; R0805
SV1: Input; MA06-1
SV2: Output; MA06-1
T1, T2, T3, T4, T5, T6, T7, T8, T9, T10: 2N6387G; TO220V
U$1: TEENSY_3.1_ALL_PINS_AND_PADS; TEENSY3_ALL_PINS_&_PADS

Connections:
3.3V: U$1.3.3V, U$1.3.3V1 (3.3V), U$1.3.3V2 (3.3V)
+5V: SV1.2, SV2.2, U$1.VIN
ADDR_LATCH_I: SV1.5, U$1.1 (1/TX1/T)
ADDR_LATCH_O: SV2.5, U$1.2
AGND: R21.1, U$1.AGND
AREF: U$1.AREF
CHIME1: T1.1 (B), U$1.3 (3/CAN-TX/PWM)
CHIME2: T2.1 (B), U$1.4 (4/CAN-RX-PWM)
CHIME3: T3.1 (B), U$1.5 (5/PWM)
CHIME4: T4.1 (B), U$1.6 (6/PWM)
CHIME5: T5.1 (B), U$1.9 (9/RX2/PWM)
CHIME6: T6.1 (B), U$1.10 (10/TX2/PWM)
CHIME7: T7.1 (B), U$1.20/A6 (20/A6/PWM)
CHIME8: T8.1 (B), U$1.21/A7 (21/A7/PWM)
CHIME9: T9.1 (B), U$1.22/A8 (22/A8/T/PWM)
CHIME10: T10.1 (B), U$1.23/A9 (23/A9/T/PWM)
FEEDBACK1: C1.1, R1.2, R2.2, U$1.A12
FEEDBACK2: C2.1, R3.2, R4.2, U$1.26 (26/A15)
FEEDBACK3: C3.1, R5.2, R6.2, U$1.27 (27/A16)
FEEDBACK4: C4.1, R7.2, R8.2, U$1.28 (28/A17)
FEEDBACK5: C5.1, R9.2, R10.2, U$1.RESET/DAC (A14/DAC)
FEEDBACK6: C6.1, R11.2, R12.2, U$1.14/A0
FEEDBACK7: C7.1, R13.2, R14.2, U$1.15/A1 (15/A1/T)
FEEDBACK8: C8.1, R15.2, R16.2, U$1.16/A2 (16/A2/T)
FEEDBACK9: C9.1, R17.2, R18.2, U$1.17/A3 (17/A3/T)
FEEDBACK10: C10.1, R19.2, R20.2, U$1.30 (30/A19/SDA1)
GND: C1.2, C2.2, C3.2, C4.2, C5.2, C6.2, C7.2, C8.2, C9.2, C10.2, J11.P$1, J11.P$2, R2.1, R4.1, R6.1, R8.1, R10.1, R12.1, R14.1, R16.1, R18.1, R20.1, R21.2, SV1.1, SV2.1, T1.3 (E), T2.3 (E), T3.3 (E), T4.3 (E), T5.3 (E), T6.3 (E), T7.3 (E), T8.3 (E), T9.3 (E), T10.3 (E), U$1.GND, U$1.GND1 (GND), U$1.GND2 (GND)
HS1: J1.P$1, J1.P$2, R1.1, T1.2 (C)
HS2: J2.P$1, J2.P$2, R3.1, T2.2 (C)
HS3: J3.P$1, J3.P$2, R5.1, T3.2 (C)
HS4: J4.P$1, J4.P$2, R7.1, T4.2 (C)
HS5: J5.P$1, J5.P$2, R9.1, T5.2 (C)
HS6: J6.P$1, J6.P$2, R11.1, T6.2 (C)
HS7: J7.P$1, J7.P$2, R13.1, T7.2 (C)
HS8: J8.P$1, J8.P$2, R15.1, T8.2 (C)
HS9: J9.P$1, J9.P$2, R17.1, T9.2 (C)
HS10: J10.P$1, J10.P$2, R19.1, T10.2 (C)
I2C_SCL: SV1.3, SV2.3, U$1.19/A5 (19/A5/T/SCL0)
I2C_SDA: SV1.4, SV2.4, U$1.18/A4 (18/A4/T/SDA0)
PS_EN: SV1.6, SV2.6, U$1.0 (0/RX1/T)
VBAT: U$1.VBAT
VUSB: U$1.VUSB

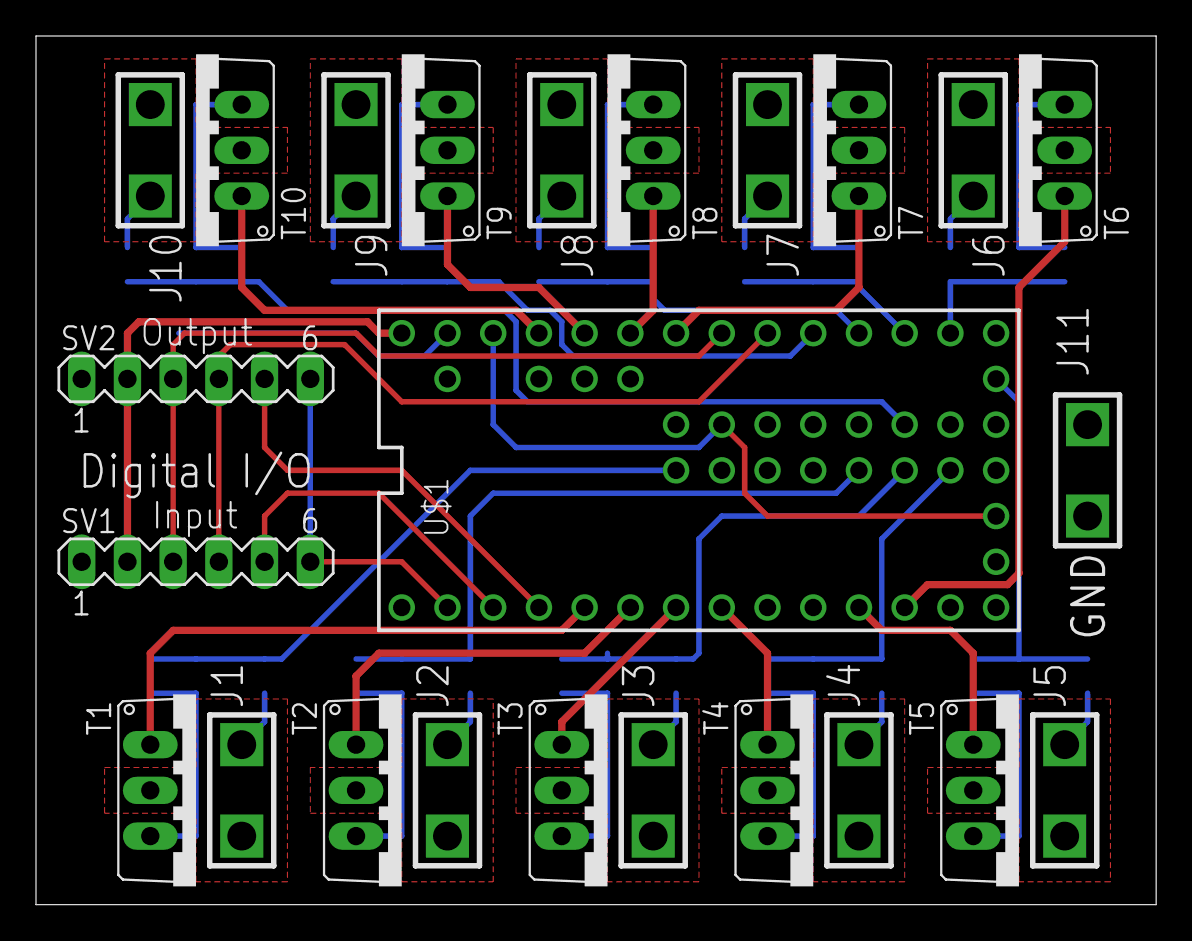
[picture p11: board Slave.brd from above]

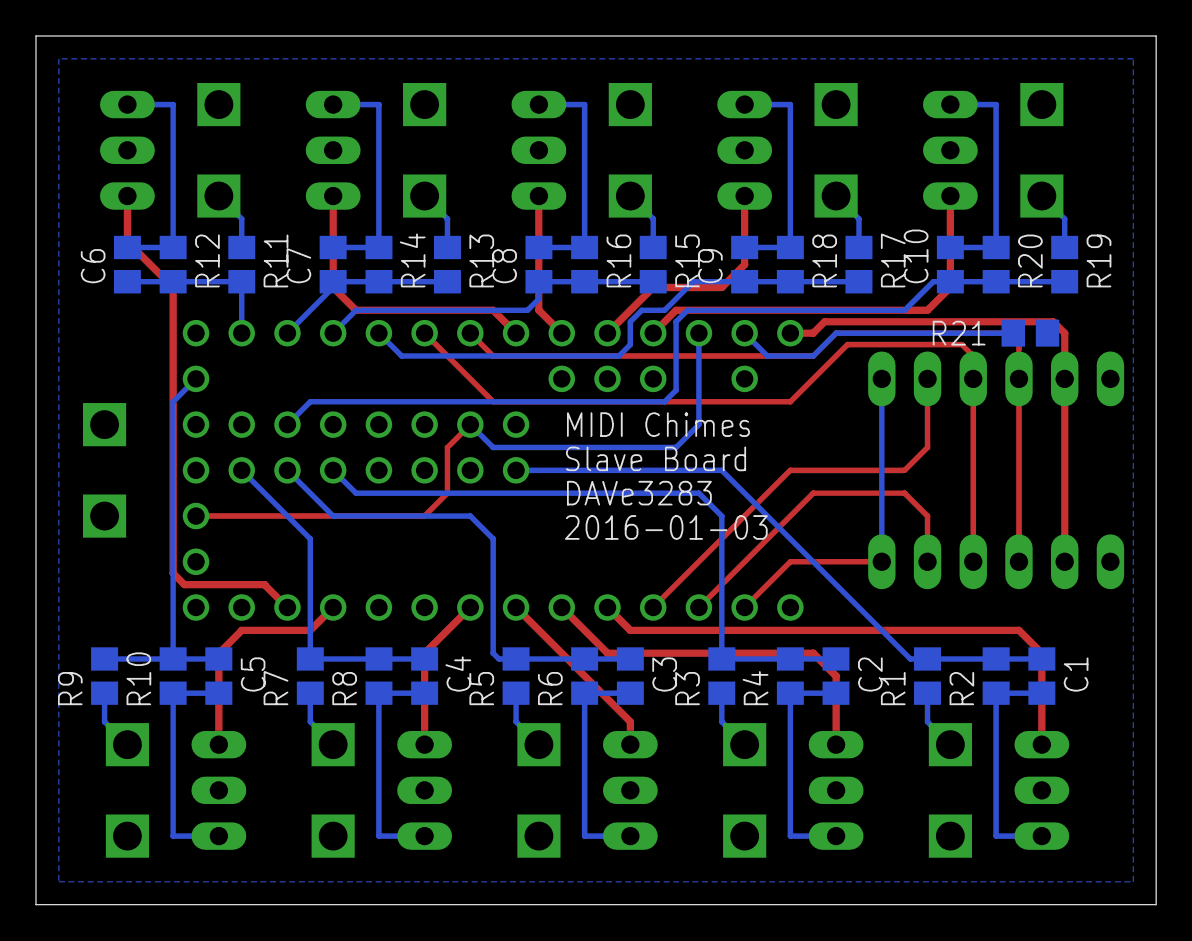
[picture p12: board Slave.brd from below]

Board: 2 copper layers, 62.2 x 48.3 mm, 55 parts (31 on the bottom side), 39 nets.

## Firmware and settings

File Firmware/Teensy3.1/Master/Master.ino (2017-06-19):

// -----------------------------------------------------------------------------
// Master.ino
//
// The master Teensy that runs the MIDI chimes.
// This Teensy is responsible for running the display, USB and physical MIDI,
// address auto-assignment, etc.
//
// TODO:
// * Limit max simultaneous chime strikes to avoid overloading PSU
// * See Notes/MIDI.md for channel, program, and OUT/THRU information.
// * Implement settings
//   * Storing them in EEPROM is fine
// * Implement channel selection
// * Implement MIDI OUT and THRU
// * Handle per-channel volume?
// * Make the display do useful things
//   * Show input source (USB or physical MIDI)
//   * Options
//     * Override velocity to master volume vs. scale velocity 0-master
//       * Default should probably be scale
//     * Physical MIDI port is OUT or THRU
//     * Pass USB MIDI to physical MIDI OUT? (or should I always just do this?)
// * Read from SD card
//   * Basic file browser?
// * Playback of MIDI files (from SD card)
//   * Play doorbel tone from sd "doorbell" folder :P
// * Stop other playback while doorbell is playing?
// -----------------------------------------------------------------------------

#define VERSION_MAJOR 0
#define VERSION_MINOR 5
#define VERSION_REVISION 1

// Comment this line out if using the resistive touchscreen layer
//#define CAPACITIVE_TS

// -----------------------------------------------------------------------------
// Includes
// -----------------------------------------------------------------------------

// Core I/O (display, slaves, SD card)
#include <SPI.h>
#include <i2c_t3.h>
#include <ILI9341_t3.h>
#include <SdFat.h>

// GUI
extern "C"
{
  #include "ugui.h"
}

// Touchscreen driver
#ifdef CAPACITIVE_TS
  #include <Adafruit_FT6206.h>
#else
  #include <Adafruit_STMPE610.h>
#endif

// Fonts
#include "FontAwesome_mod_50X40.h"

// Blue Screen of Death :P
#include "bsod_win10.h"

// Config file
#include "config_file.h"

// Slave status message parsing
#include "slave_status.h"

using namespace midi_chimes;

// -----------------------------------------------------------------------------
// Constants
// -----------------------------------------------------------------------------

// I²C config
const uint8_t i2c_slave_base_address(0x10); // Starting address for slaves
const uint8_t i2c_slave_ack(0x06); // ACK sentinel expected from the slaves

// Settings file
const char ini_filename[] = "/Settings.ini";

// Note map (loaded from config file)
// MIDI spec only allows a maximum of 128 notes, so we will just build a map of
// all possibilities
slave_note_map note_map[128] = {};
const size_t notes_per_slave(10);

// Power Supply
const float minimum_ps_voltage(10.0f); // Minimum voltage to consider PS working
const size_t max_notes_active(10); // Maximum simultaneous notes to not overload PS

// Duty Cycle Settings
const uint8_t pwm_bits(12); // 0 - 4095 <-- must match slaves!
const uint16_t maximum_dc((1 << pwm_bits) - 1);

// Pins
const uint8_t spi_mosi_pin(11);
const uint8_t spi_miso_pin(12);
const uint8_t spi_sck_pin(14);
const uint8_t sd_cs_pin(21);
const uint8_t doorbell_pin(2);
const uint8_t ps_en_pin(8);
const uint8_t addr_latch_pin(10);
const uint8_t led_pin(13);

// Touch Screen
// Pins
const uint8_t lcd_reset_pin(17);
const uint8_t lcd_cs_pin(15);
const uint8_t lcd_dc_pin(9);
const uint8_t touch_cs_pin(20);
// Backlight
const uint8_t lcd_backlight_pin(23);
const uint8_t lcd_bl_pwm_bits(16);
const uint32_t lcd_bl_pwm_freq(549); // Hz
#ifndef CAPACITIVE_TS
// Resistive Touch Screen Calibration
const uint16_t ts_min_x( 150);
const uint16_t ts_max_x(3800);
const uint16_t ts_min_y( 130);
const uint16_t ts_max_y(4000);
#endif

// Timeouts
const uint32_t blink_time(20000); // microseconds
const uint32_t ps_en_toggle_time(1000); // microseconds
const uint32_t ps_settle_time(500); // milliseconds
const uint32_t note_strike_time(90); // milliseconds <-- must match slaves!
const uint32_t slave_post_timeout(3000); // milliseconds (after ps_settle_time)
const uint32_t slave_status_interval(1000); // milliseconds
const uint32_t sleep_time(5 * 60 * 1000); // milliseconds

// Backlight brightness
const uint16_t lcd_bl_pwm_max(0xFFFF);
const uint16_t lcd_bl_pwm_min(0x0C00);
const uint16_t lcd_bl_pwm_step((lcd_bl_pwm_max - lcd_bl_pwm_min) / ps_settle_time);
// We want to ramp up the backlight while we wait for the power supply to settle.

// Graphics settings
const uint16_t console_bg(0x0000); // Windows 98+ #000000 --> RGB565
const uint16_t console_fg(0xC618); // Windows XP+ #C0C0C0 --> RGB565 (98 used #A8A8A8)
const uint16_t background_color(ILI9341_YELLOW);
const uint16_t button_text_disabled(C_GRAY);
const uint16_t selected_color(C_GREEN);

// Icons
const char fa_icon_settings[] = "u";      // Sliders
const char fa_icon_vol_dn[] = "F";        // Volume Down
const char fa_icon_vol_up[] = "G";        // Volume Up
const char fa_icon_level_up[] = "]";      // Level Up
const char fa_icon_level_down[] = "^";    // Level Down
const char fa_icon_folder_closed[] = "_"; // Folder, Closed (solid)
const char fa_icon_folder_open[] = "a";   // Folder, Open (solid)
const char fa_icon_file_generic[] = "d";  // File, Generic (outline)
const char fa_icon_file_picture[] = "k";  // File, Picture / Image (outline)
const char fa_icon_file_sound[] = "m";    // File, Sound / Music (outline)
const char fa_icon_file_config[] = "o";   // File, Code / Config (outline)
const char fa_icon_sleep_leaf[] = "C";    // Leaf (sleep)
const char fa_icon_bell[] = "Y";          // Bell
const char fa_icon_music[] = "D";         // Music Note (Beamed)
const char fa_icon_usb[] = "y";           // USB Logo
const char fa_icon_info[] = "S";          // Information (in circle)
const char fa_icon_exclaim[] = "!";       // Exclamation (in circle)
const char fa_icon_question[] = "?";      // Question (in circle)

// MIDI Commands
const uint8_t midi_cmd_note_off(0x80);
const uint8_t midi_cmd_note_on(0x90);
const uint8_t midi_cmd_aftertouch(0xA0);
const uint8_t midi_cmd_control_change(0xB0);
const uint8_t midi_cmd_program_change(0xC0);
const uint8_t midi_cmd_aftertouch_mono(0xD0);
const uint8_t midi_cmd_pitch_bend(0xE0);
const uint8_t midi_cmd_system_exclusive(0xF0);
const uint8_t midi_cmd_end_exclusive(0xF7);

// MIDI Programs (Instruments)
const uint8_t midi_prog_tubular_bells(0xE);

// Power state of master
enum power_state_t
{
  awake,
  sleep,
  awake_to_sleep_transition,
  sleep_to_awake_transition,
} power_state;

// Doorbell song (hard coded for now, TODO: play off SD card)
// E5 C5 D5 G4, G4 D5 E5 C5 works on these chimes, but one octave lower might too
const uint8_t  doorbell_song_notes[] = {  76,  72,  74,  67,   67,  74,  76,  72, }; // or 64,60,62,55,55,62,64,60
const uint32_t doorbell_note_delay[] = {   0, 500, 500, 500, 1000, 500, 500, 500, }; // milliseconds before starting this note
const size_t   doorbell_song_length(sizeof(doorbell_song_notes) / sizeof(*doorbell_song_notes));

// -----------------------------------------------------------------------------
// Declarations
// -----------------------------------------------------------------------------
// void OnNoteOff(uint8_t channel, uint8_t note, uint8_t velocity); // Not needed
void OnNoteOn(uint8_t channel, uint8_t note, uint8_t velocity);
// void OnVelocityChange(uint8_t channel, uint8_t note, uint8_t velocity);
void OnControlChange(uint8_t channel, uint8_t control, uint8_t value);
void OnProgramChange(uint8_t channel, uint8_t program);
// void OnAfterTouch(uint8_t channel, uint8_t pressure);
// void OnPitchChange(uint8_t channel, int pitch);
void OnSystemExclusive(const uint8_t* data, uint16_t length, bool complete);
// void OnRealTimeSystem(uint8_t realtimebyte);
// void OnTimeCodeQuarterFrame(uint16_t data);

// How many notes are available without exceeding max_notes_active?
size_t notes_available();

// Scale a MIDI velocity (7-bit) to our 12-bit velocity
uint16_t scale_midi_velocity(const uint8_t& midi_velocity, const uint8_t& note);

// Send a chime strike command to a slave
void send_chime(const uint8_t& address, const uint8_t& channel, const uint16_t& velocity);

// Gets the slave address and channel on the slave for a given MIDI note
bool get_slave_and_channel(const uint8_t& midi_note, uint8_t& slave_address_out, uint8_t& slave_channel_out);

// Adjust Master Volume
void adjust_master_volume(int8_t change); // Adjust up/down by the specified amount
void set_master_volume(const int8_t& volume); // Set volume the specified value (0 - 100)

// I²C functions
uint8_t i2c_addr_auto_assign(); // Auto-assign I²C addresses to slaves
bool i2c_check_ack(const uint8_t& address); // Check for ack from slave
void i2c_check_result(const uint8_t& i2c_result, const uint8_t& address, const int& line);

// Doorbell Functions
void doorbell_isr(); // Doorbell physically pressed
void doorbell_update(); // Update doorbell software state, start chiming, etc.

// Get slave status
bool get_slave_status(const uint8_t& address, slave_status& state);
void validate_slave_config(const uint8_t& slave, const slave_status& status);
void validate_slave_status(const uint8_t& slave, const slave_status& status);
void next_slave(); // Update current_slave to the next slave

// Power management functions
void ps_update(); // Toggle PS_EN when required to activate power supply
void power_activity(); // Activity detected, exit sleep mode & reset timer
void power_state_update(); // Update power state, display brightness, etc.
bool backlight_up(); // Increases backlight
bool backlight_down(); // Decreases backlight
void begin_sleep(); // Begin sleep process
void begin_wake(); // Begin wakeup process
void wake_complete(); // Finish wakeup process

// µGUI
void UserPixelSetFunction(UG_S16 x, UG_S16 y, UG_COLOR c);
// µGUI Hardware Acceleration
UG_RESULT _HW_DrawLine(UG_S16 x1, UG_S16 y1, UG_S16 x2, UG_S16 y2, UG_COLOR c);
UG_RESULT _HW_FillFrame(UG_S16 x1, UG_S16 y1, UG_S16 x2, UG_S16 y2, UG_COLOR c);

// Main window
void draw_main_window();
void main_callback(UG_MESSAGE* msg);

// Settings window
void draw_settings_window();
void settings_callback(UG_MESSAGE* msg);

// About window
void draw_about_window();
void about_window_callback(UG_MESSAGE* msg);

// Sleep window
void draw_sleep_window();
void sleep_callback(UG_MESSAGE* msg);

// Doorbell window
void draw_doorbell_window();
void doorbell_callback(UG_MESSAGE* msg);


// -----------------------------------------------------------------------------
// Globals
// -----------------------------------------------------------------------------

// User settings
uint8_t our_channel(0); // Current channel (0 = all, 1-16)
int8_t master_volume(100); // Master volume (0-100, 0 means mute, steps of 10)
bool override_velocity(false); // Override velocity to master volume (true), or scale it by master volume (false)
bool play_all_programs(false); // Play all programs (instruments), or just Tubular Bells?

// Slave status
uint8_t slaves_found(0); // How many slaves we found during POST
uint8_t current_slave(0); // The current slave we are checking the status of
size_t notes_active(0); // How many notes are currently being struck

// Power supply
bool ps_enabled(true); // Is the power supply enabled?
bool ps_en_high(false); // Is the PS_EN pin high currently?

// Backlight
uint16_t backlight_pwm(lcd_bl_pwm_max);

// MIDI state
bool play_this_program[17]; // Do we play notes for the current program?
bool midi_master_volume_14bit(false); // Is the master volume message 14-bit? (or just 7-bit)
bool midi_receiving_sysex(false); // Are we currently receiving a system exclusive message?
uint8_t midi_sysex_buffer[8] = {}; // Buffer long enough to hold the longest message we will handle
const size_t midi_sysex_buffer_size(sizeof(midi_sysex_buffer) / sizeof(*midi_sysex_buffer));
size_t midi_sysex_message_length(0); // Length of the last received system exclusive message (including start & end marker)

// Doorbell
volatile bool doorbell_pressed(false); // Set to true in ISR when the doorbell is pressed
bool doorbell_playing(false); // True while we are playing the doorbell song
size_t doorbell_song_index(0); // Used to play through the hard coded song, will be removed when we switch to MIDI files

// Timers
elapsedMicros ps_en_timer;
elapsedMillis sleep_timer;
elapsedMillis doorbell_timer;
elapsedMillis slave_status_timer;
elapsedMillis note_strike_timer[max_notes_active];

// Serial IO
HardwareSerial midi = HardwareSerial();
HardwareSerial3 ser = HardwareSerial3(); // For debug

// SD Card
SdFat sd;
SdFile file;
SdFile dirFile;

// Touch Screen
ILI9341_t3 tft = ILI9341_t3(lcd_cs_pin, lcd_dc_pin, lcd_reset_pin, spi_mosi_pin, spi_sck_pin, spi_miso_pin); // TFT LCD
#ifdef CAPACITIVE_TS
  Adafruit_FT6206 ts = Adafruit_FT6206();  // Using default Arduino I²C pins?
#else
  Adafruit_STMPE610 ts = Adafruit_STMPE610(touch_cs_pin); // Touch sensor
#endif

// µGUI
UG_GUI gui;

// Main Window
UG_WINDOW main_window;
UG_BUTTON main_window_button_settings;
UG_BUTTON main_window_button_about;
UG_BUTTON main_window_button_vol_dn;
UG_BUTTON main_window_button_vol_up;
UG_PROGRESSBAR main_window_prb_volume;
UG_OBJECT main_window_buffer[5];
char volume_text_buffer[5] = { 0 };
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
void loop()
{
  // Manage power state (sleep)
  power_state_update();

  // Handle doorbell
  doorbell_update();

  // Handle power supply
  ps_update();

  // Check slave status (only while awake)
  if ((power_state == awake) && (slave_status_timer >= slave_status_interval))
  {
    // Reset the timer
    slave_status_timer = 0;

    // Determine what slave to work with
    const uint8_t address(i2c_slave_base_address + current_slave);
    slave_status status;
    if (!get_slave_status(address, status))
    {
      draw_BSOD(tft);
      tft.println("Lost communication with slave board!");
      tft.print(  "Slave: ");
      tft.println(current_slave + 1);
      tft.println();
      tft.println("Please verify all cables are connected securely.");
      halt_system();
    }
    validate_slave_status(current_slave, status);
    next_slave();
  }

  // Handle USB MIDI messages
  usbMIDI.read();

  // Handle hardware MIDI messages
  int midi_bytes_available;
  while ((midi_bytes_available = midi.available()) > 0)
  {
    power_activity();

    const uint8_t status(midi.peek());

    // Handle MIDI system exclusive data
    if (midi_receiving_sysex)
    {
      midi.read(); // Drop the byte from the buffer

      // Look for end of message
      if (status == midi_cmd_end_exclusive)
      {
        midi_receiving_sysex = false;
        const bool have_full_message(midi_sysex_message_length <= midi_sysex_buffer_size);
        OnSystemExclusive(
          midi_sysex_buffer,
          have_full_message ? midi_sysex_message_length : midi_sysex_buffer_size,
          have_full_message);
        continue;
      }

      // Store the message until the buffer is full
      if (midi_sysex_message_length < midi_sysex_buffer_size)
      {
        midi_sysex_buffer[midi_sysex_message_length] = status;
      }
      midi_sysex_message_length++;

      // Move on to the next byte
      continue;
    }

    // Drop non-command data until the buffer starts with a command
    if (status < 0x80) // All command bytes start with a 1
    {
      midi.read(); // Drop the byte from the buffer
      continue;
    }

    // Parse
    const uint8_t command( status & 0xF0);      // Mask off command
    const uint8_t channel((status & 0x0F) + 1); // Mask off channel, add 1 to match usbMIDI

    // Find how many data bytes we need
    int required_data_bytes(0);
    switch (command)
    {
    // 2 byte commands
    case midi_cmd_note_off:
    case midi_cmd_note_on:
    case midi_cmd_aftertouch:
    case midi_cmd_control_change:
    case midi_cmd_pitch_bend:
      required_data_bytes = 2;
      break;

    // 1 byte commands
    case midi_cmd_program_change:
    case midi_cmd_aftertouch_mono:
      required_data_bytes = 1;
      break;

    // System Exclusive
    case midi_cmd_system_exclusive:
      required_data_bytes = 0; // We start dumping it to a buffer
      break;

    // Unknown commands
    default:
      break;
    }

    // Verify we have enough data
    if (midi_bytes_available <= required_data_bytes)
    {
      break;
    }

    // Read command & data
    midi.read(); // Drop command from buffer, we already know what it is
    uint8_t midi_buffer[required_data_bytes];
    bool valid(true);
    for (int i(0); i < required_data_bytes; ++i)
    {
      // Validate byte is not a command (data values all start with 0)
      if (midi.peek() >= 0x80)
      {
        // We didn't get the correct number of data bytes! Drop what we have so
        // far and start again on the next command
        valid = false;
        break;
      }

      // Read the data byte
      midi_buffer[i] = midi.read();
    }
    if (valid)
    {
      // Call appropriate function
      switch (command)
      {
      // Note On
      case midi_cmd_note_on:
        OnNoteOn(channel, midi_buffer[0], midi_buffer[1]);
        break;

      // Control Change (channel volume)
      case midi_cmd_control_change:
        OnControlChange(channel, midi_buffer[0], midi_buffer[1]);
        break;

      // Program change
      case midi_cmd_program_change:
        OnProgramChange(channel, midi_buffer[0]);
        break;

      // System Exclusive
      case midi_cmd_system_exclusive:
        midi_receiving_sysex = true;
        midi_sysex_message_length = 0;
        break;

      // Not implemented
      case midi_cmd_note_off:
      case midi_cmd_aftertouch:
      case midi_cmd_aftertouch_mono:
      case midi_cmd_pitch_bend:
        break;

      // Unknown commands
      default:
        break;
      }
    }
  }

  // Handle GUI & Touch
  const bool touched(ts.touched());
#ifdef CAPACITIVE_TS
  if (touched)
  {
    power_activity();

    // Retrieve a point
    TS_Point p = ts.getPoint();

    // Rotate the screen
    const int y(p.x);
    const int x(tft.width() - p.y);

    // Handle touch event
    UG_TouchUpdate(x, y, TOUCH_STATE_PRESSED);
  }
  else
  {
    UG_TouchUpdate(-1, -1, TOUCH_STATE_RELEASED);
  }
#else // Resistive touch screen
  if (!ts.bufferEmpty())
  {
    power_activity();

    // Retrieve a point
    TS_Point p = ts.getPoint();

    // Scale using the calibration #'s and rotate coordinate system
    p.x = map(p.x, ts_min_y, ts_max_y, 0, tft.height());
    p.y = map(p.y, ts_min_x, ts_max_x, 0, tft.width());
    const int x(p.y);
    const int y(tft.height() - p.x);

    // Handle touch event
    UG_TouchUpdate(x, y, touched ? TOUCH_STATE_PRESSED : TOUCH_STATE_RELEASED);
  }
  else
  {
    if (!touched)
    {
      // Indicate touch released
      UG_TouchUpdate(-1, -1, TOUCH_STATE_RELEASED);
    }
  }
#endif

  // Update the GUI
  UG_Update();
}

void OnNoteOn(uint8_t channel, uint8_t note, uint8_t velocity)
{
  power_activity();

  // MIDI spec allows turning a note off by sending a note on with velocity = 0
  // We don't care about note off ;)
  if (velocity == 0)
  {
    return;
  }

  // Verify the channel is valid
  if (channel > 16)
  {
    return;
  }

  // Are we handling this channel and/or program (instrument)?
  const bool channel_valid((our_channel == 0) || (channel == our_channel));
  const bool play_channel(play_all_programs || play_this_program[channel]);
  if (channel_valid && play_channel)
  {
    // Lookup note
    uint8_t slave_address, slave_channel;
    if (get_slave_and_channel(note, slave_address, slave_channel))
    {
      digitalWrite(led_pin, HIGH); // diagnostics
      send_chime(slave_address, slave_channel, scale_midi_velocity(velocity, note));
      digitalWrite(led_pin, LOW); // diagnostics
    }
  }
  else
  {
    // TODO: MIDI out/thru
  }
}

void OnControlChange(uint8_t channel, uint8_t control, uint8_t value)
{
  // TODO: MIDI out/thru

  // Skip other channels
  if (our_channel && (channel != our_channel))
  {
    return;
  }

  // Handle control change messages
  // See http://nickfever.com/music/midi-cc-list for more messages
  switch (control)
  {
  // Adjust system volume
  case   7: // Volume
  case  11: // Expression
    set_master_volume(static_cast<int>(value) * 100 / 127);
    break;

  // Reset
  case 121: // Reset All Controllers
    // TODO: what needs reset?
    break;

  // Not implemented
  default:
    break;
  }
}

void OnProgramChange(uint8_t channel, uint8_t program)
{
  power_activity();

  // Verify the channel is valid
  if ((channel < 1) || (channel > 16))
  {
    return;
  }

  play_this_program[channel] = (program == midi_prog_tubular_bells);
  // TODO: MIDI out/thru
}

void OnSystemExclusive(const uint8_t* data, uint16_t length, bool complete)
{
  if (!complete)
  {
    // Can't do anything with part of a message
    // We don't buffer larger messages; the buffer is sized for the largest message we expect
    return;
  }

  // Handle Master Volume message
  // http://www.recordingblogs.com/sa/tabid/88/Default.aspx?topic=MIDI+Master+Volume+message
  if ((length == 6) &&      // Expected length is 6 + start & end commands
      (data[0] == 0x7F) &&  // Realtime
      (data[1] == 0x7F) &&  // SysEx channel, 0x7F means all/disregard
      (data[2] == 0x04) &&  // Sub-ID - Device Control
      (data[3] == 0x01))    // Sub-ID - Master Volume
  {
    // const uint8_t system_exclusive_channel(data[1]);
    const uint16_t volume_lower_bits(data[4] & 0x7F);
    const uint16_t volume_upper_bits(data[5] & 0x7F);

    // Check for 14-bit resolution
    if (volume_lower_bits)
    {
      midi_master_volume_14bit = true;
    }

    // Set volume
    if (midi_master_volume_14bit)
    {
      // 14-bit
      const uint16_t volume_14bit((volume_upper_bits << 7) & volume_lower_bits);
      set_master_volume(volume_14bit * 100 / ((1 << 14) - 1));
    }
    else
    {
      // 7- bit
      set_master_volume(volume_upper_bits * 100 / ((1 << 7) - 1));
    }
  }
}
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

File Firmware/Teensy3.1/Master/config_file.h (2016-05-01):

// Configuration File Handling

// Header guard
#ifndef _CONFIG_FILE_H_
#define _CONFIG_FILE_H_

#include <stdint.h>
#include <IniFile.h>

namespace midi_chimes
{

// Maps notes to the respective slave
struct slave_note_map
{
    // I2C address of the slave
    uint8_t slave_address = 0;

    // Channel (port) on the slave for this note
    uint8_t channel = 0;

    // Calibration values for this note
    float calibration_min = 0.0f;
    float calibration_max = 1.0f;
};

class config_file
{
public:
    config_file(const char* filename);
    ~config_file();

    // Open the INI file
    bool open();

    // Validate the INI file
    bool validate();

    // Load global / required values
    bool load_globals();

    // Get the number of slave configs in the INI file
    bool get_slave_count(int8_t& slave_count);

    // Get the notes mapped to the given slave
    bool get_slave_notes(const int8_t& slave_no, int8_t notes[10]);

    // Get the calibration (0.0 - 1.0) for the given note, if present in the INI
    bool get_note_calibration(const int8_t& note, float& min, float& max);
    bool get_note_calibration_min(const int8_t& note, float& calibration);
    bool get_note_calibration_max(const int8_t& note, float& calibration);

    // Print the INI error message from the errNo provided
    static void print_ini_error_message(Print& display, const uint8_t& errNo, bool eol = true);

    // Print the error message for the current error number
    void print_ini_error_message(Print& display, bool eol = true) const;

    // Lookup a note number (0-127) from a string, NULL for invalid note number
    static const char* lookup_note_name(const int8_t& note);

private:
    // Holds the INI file used to store config settings
    IniFile ini;

    // Default minimum PWM %
    float calibration_min_default;

    // Buffer for reading INI file
    const static size_t ini_buffer_len = 84;
    char ini_buffer[ini_buffer_len];

    // Maximum number of slaves
    const static int8_t max_slaves = 13;
    // MIDI allows 128 notes, and each slave can handle 10, so we need up to 13

    // Parse a string ("61" or "C4#") into the MIDI note number, -1 for invalid.
    static int8_t parse_note(const char* note);

    // Parse a percentage string (0.0 - 100.0%) to a float (0.0-1.0)
    static bool parse_percentage(char* str, float& percentage);

    // Checks if the provided value is a number
    static bool is_number(const char* str);
    static bool is_number(const char& c);
};

} // namespace midi_chimes
#endif // ifndef _CONFIG_FILE_H_

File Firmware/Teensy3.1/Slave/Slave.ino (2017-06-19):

// -----------------------------------------------------------------------------
// Slave.ino
//
// Program for all the slave Teensy units that run the MIDI chimes coils.
// Each slave is responsible for running a number of chimes, and keeping them
// from overheating.
//
// TODO:
// * Should I implement some sort of cumulative current limit to protect the PCB?
//   If each coil is 2A, and all 10 are told to fire, that's 20A through the PCB traces...
//   Now imagine if they are 10A each O_o
// -----------------------------------------------------------------------------

// -----------------------------------------------------------------------------
// Includes
// -----------------------------------------------------------------------------
#include <i2c_t3.h>


// -----------------------------------------------------------------------------
// Constants
// -----------------------------------------------------------------------------

// General I/O pins
const uint8_t ps_enable_pin(0);     // Power supply enable pin
const uint8_t addr_latch_i_pin(1);  // Address latch input pin
const uint8_t addr_latch_o_pin(2);  // Address latch output pin
const uint8_t led_pin(13);          // LED pin

// PWM pins used by the chime coils
const uint8_t chime_pins[] =
{
   3, // Channel 1
   4, // Channel 2
   5, // Channel 3
   6, // Channel 4
   9, // Channel 5
  10, // Channel 6
  20, // Channel 7
  21, // Channel 8
  22, // Channel 9
  23, // Channel 10
};
const uint8_t num_channels(sizeof(chime_pins) / sizeof(*chime_pins));

// Analog pins used for feedback
const uint8_t feedback_pins[num_channels] =
{
  A12, // Channel 1 (on back)
  A15, // Channel 2 (pin 26 on back)
  A16, // Channel 3 (pin 27 on back)
  A17, // Channel 4 (pin 28 on back)
  A14, // Channel 5 (bottom row)
   A0, // Channel 6 (pin 14)
   A1, // Channel 7 (pin 15)
   A2, // Channel 8 (pin 16)
   A3, // Channel 9 (pin 17)
  A19, // Channel 10 (pin 30 on back)
};

// Timeouts
const uint32_t strike_time( 90); // milliseconds
const uint32_t settle_time(155); // milliseconds
const uint32_t blink_time(  20); // milliseconds
// Power supply timeouts
const uint32_t ps_stable_time(2500); // milliseconds, datasheet spec for power supply
const uint32_t ps_toggle_time( 100); // milliseconds, datasheet spec for watchdog

// PWM Config
const uint8_t pwm_bits(12);
const uint32_t pwm_freq(8789); // Hz

// Voltage Divider
// I am using a divider of 160k and 10k, giving (160k+10k):10k, or 17:1.
const float divider_ratio(17.0f);
// We are using the Teensy's 1.2V stable internal reference for better accuracy.
// That means we can read 0 - 20.4 volts.

// We can do a 13-bit read on the Teensy 3.1 & 3.2
const uint8_t analog_read_bits(13);

// Transistor characteristics (for diagnostics)
// Voltages based on experimental & datasheet values for 2N6387 transistor & my coils
const float transistor_Vce_drop(  1.1f); // Transistor V_CE when on with my coils (measured value, datasheet spec is <= 2V)
const float connected_min_voltage(0.1f); // Voltages above this at startup are considered connected
const float shorted_voltage(      1.5f); // Voltages below this are considered shorted (regardless of ps_setpoint)
// Error limits (determined experimentally)
const float base_error(          0.05f); // Base allowed error during strike / settle
const float per_strike_error(    0.05f); // Extra error allowed during strike for each additional coil on simultaneously
const float shorted_percent_ps_setpoint(0.75f); // Voltages lower than this % of ps_setpoint when commanded off are considered shorted
const float open_percent_ps_setpoint(   0.98f); // Voltages higher than this % of ps_setpoint when commanded on are considered open circuit

// States channels can be in
enum channel_state_t : uint8_t
{
  channel_working = 0,
  channel_disconnected = 1,
  channel_failed_short = 2,
  channel_failed_open = 3,
};

// State power supply can be in
enum ps_state_t
{
  stable, // has been on for at least ps_stable_time
  stabilizing, // has just turned on
  disabled, // appears to be disabled
};


// -----------------------------------------------------------------------------
// Thermal Management
// -----------------------------------------------------------------------------

// Maximum number of strikes (per chime) in a rolling window
const uint8_t max_strikes(60);

// Cooldown period (in ms).
// Every time this expires, an additional strike is allowed, up to max_strikes.
const uint16_t cooldown_period(1000);


// -----------------------------------------------------------------------------
// Declarations
// -----------------------------------------------------------------------------
// ISRs
void i2c_startup(size_t numBytes);
void i2c_receive(size_t numBytes);
void i2c_startup_ack();
void i2c_status_requested();
void ps_en_isr();

// Update power supply state
void ps_state_update();

// I2C address auto-assignment procedure
void i2c_addr_auto_assign();

// Startup diagnostics
void measure_ps_voltage();

// Strike a chime (handles thermals, settle time, etc.)
void strike_chime(const uint8_t& channel, const uint16_t& duty_cycle);

// Count how many channels are currently striking
uint8_t num_striking();

// Read the voltage on the given channel
float read_voltage(const uint8_t& channel);

// Check if a channel is in the expected range
bool is_in_range(const float& error);

// Check channel for shorts
bool is_shorted(const float& voltage);

// Handle a shorted channel (disable power supply)
void handle_shorted(const uint8_t& channel);

// Check channel for opens
bool is_open(const float& voltage);

// Verify transistors turn on/off
bool verify_on(const uint8_t& channel);
bool verify_off(const uint8_t& channel);

// Debug
void print_state(Print& out, const channel_state_t& state);
void print_state(Print& out, ps_state_t state);

// -----------------------------------------------------------------------------
// Globals
// -----------------------------------------------------------------------------

// I2C
volatile uint8_t i2c_address(0); // Assigned during startup
volatile bool i2c_ready(false); // Only goes true once we have completed address auto-assignment routine

// Timers
elapsedMillis cooldown_timer;
elapsedMillis strike_timer[num_channels];
elapsedMillis message_blink_timer;
elapsedMillis ps_stable_timer;

// USB Debug
usb_serial_class usb = usb_serial_class();
uint8_t debug_level(0);

// Are we striking currently?
volatile bool striking[num_channels];

// What Duty Cycle (%) are we commanding for the channel?
volatile float set_dc[num_channels];

// Have we verified the voltage is reasonable (coil & transistor are working)?
volatile bool verified[num_channels];

// Thermal load limiter
volatile int8_t strikes_remaining[num_channels];
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

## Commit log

2015-08-30 Initial project structure, README, and test code.
    Includes a very simple firmware to test PWM on the Teensy,
    allowing me to determing PWM parameters that work well on
    the chimes with the transistors I have.
2015-08-30 Add notes on PIC pin usage.
    Fix typo in README.
2015-08-30 Got PWM settings from PIC16F1503 datasheet.
    Now I can see which settings work best on the chimes.
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2015-10-25 Update part config to enable auto-assignment of address.
    Add pin 6 as RC4 input for address latch.
    Change timer frequency so PWM is at 7.8125 kHz.
2016-01-22 Switch to using all Teensys due to time constraints.
    Also because MPLABX sucks.
2016-01-23 Update the master firmware to do a bit more.
    Add some additional notes and reference material.
2016-01-24 Add a slave framework, increase I2C data rate.
    Things more or less work at a basic level for USB MIDI.
2016-01-25 Switch from 10 channels per slave to 9 channels per slave.
    This lets me use the analog inputs to verify the transistors
    are working as expected, measure power supply voltage, etc.
2016-01-31 Add schematic, update firmware to match.
    I will just have to use the pads on the back of the Teensy,
    but I can get 10 channels per slave, which I think is worth it.
    [Slave.sch]
2016-01-31 Added initial PCB layout using Eagle.
    It passes design rule checks, but I should still go over
    it once more by hand to sanity check everything.
    [Slave.brd, Slave.sch]
2016-02-01 Update PCB layout.
    Made component names legible, and added some text to indicate what
    gets plugged in where.
    This version was sent to OHS Park. Hopefully it works!
    [Slave.brd]
2016-02-06 Update Slave firmware to match schematic.
    I ended up changing around the feedback inputs to clean up the
    PCB layout.
2016-02-13 Begin work on handling feedback to verify transistor operation.
    Address potential race conditions / critical sections.
    This might increase latency slightly, but should prevent a number of bugs.
    Make USB debug output off by default.
    I may eventually remove it entirely from the production firmware (#define?).
    [Slave.ino]
2016-02-14 Optimize chip init order to handle initial power on better.
    Fix math error when calculating ideal voltage for given PWM value.
    Fix verified[] array not being initialized at startup.
    [Slave.ino]
2016-02-14 Now checking for transistors failing open/short!
    Still a lot more to do (like turning off the power supply),
    but a large chunk of the features are now working.
    [Slave.ino]
2016-02-15 Remove i2c_t3 library local copy.
    It has been moved to my libraries folder so I can reference it from
    other libraries (like the display libraries I will use soon).
2016-02-15 Initial support for LCD touchscreen!
    Now talking to an Adafruit 1651 (2.8" LCD with resistive touch screen).
    Added initial Master schematic to Eagle as well, though it doesn't
    really have much in it yet.
    [Master.sch]
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2016-02-16 Fix for I2C Capacitive touchscreen
    Problem was physical hookup issues.
    [Master.ino]
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2016-02-26 Initial GUI tests.
    There is a problem with touch events. It responds to the
    _previous_ touch event, for some reason. I might be doing
    something wrong.
    Hardware acceleration appears to be working. I could tweak the
    ILI9341_t3 library and make it even faster, if I cared.
    [Master.ino, ugui.h]
2016-02-26 Fix resistive touch screen touch events.
    This _should_ work on the capacitive screen, but it needs tested.
    [Master.ino]
2016-02-26 Fix µGUI "click" event to actually fire.
    It works as expected for buttons. Checkboxes are untested.
    [Master.ino]
2016-02-27 Cleanup µGUI library.
    Made the library const correct, removing a ton of warnings at compile.
    Made color conversion explicit, removing a few more warnings.
    [ugui.h]
2016-02-27 Start converting things to µGUI.
    Master volume is working again, but doesn't look as good.
    There is much more to do...
    [Master.ino]
2016-02-27 Debug some SPI weirdness, improve volume buttons.
    The big problem was the SdFat-beta library. It was causing _both_
    hardware SPI clock pins to run, and limiting the frequency of
    everything to 100 kHz.
    Switching to SdFat (non-beta) and tweaking the settings got things
    working right.
    [Master.ino]
2016-02-28 Move BSOD function out of the main program.
    Switch to bitmap of Windows 10 BSOD text, instead of reproducing it
    with a font. This is currently a little larger, but now has the
    correct font, and anti-aliasing!
    [Master.ino]
2016-02-28 Switch images to a naïve RLE compression.
    This saves a lot of program space. I think I can still pull the
    trick of mirroring the :( emoticon to save even more space.
2016-02-28 Switch RLE image storage from uint16_t to uint8_t.
    This saves a bit of program memory. I think this is about as small
    as I can make these images without implementing a real compression
    algorithm.
2016-02-28 Add progress bar
    Extend uGUI to support a basic progress bar object. This object is currently
    being used for the volume bar display. Still needs a little work, but it is
    functional.
2016-02-28 Speed up how we handle volume changes.
    This avoids re-drawing buttons unless they actually change.
    [Master.ino]
2016-02-29 Initial round of logic for file browse dialog
    Converted file list from one textbox to several. This dramatically simplifies
    the highlight logic. This dialog is currently populated by debug text.
2016-03-03 Get started adding DIN MIDI In/Out plugs.
    I need to get parts in and test this.
    [Master.sch]
2016-03-04 Finish physical MIDI schematic, initial firmware.
    [Master.sch]
2016-03-04 Begin PCB for the master. Missing key features!
    It is missing the power supply connector, among other things.
    [Master.brd, Master.sch]
2016-03-05 Finish master PCB layout.
    I should verify the watchdog and power supply work as claimed
    before ordering a PCB, though.
    [Master.brd, Master.sch]
2016-03-05 Make the correct part for the watchdog.
    This is much cleaner.
    [Master.brd, Master.sch]
2016-03-08 Power connector now 4 pin. Add doorbell notes.
    The 6 pin connector was unnecessary, and risked confusion with the
    slave board connector.
    Added some notes on the cheap wireless doorbell I bought to
    integrate with the chimes.
    [Master.brd, Master.sch]
2016-03-08 Add connector for wireless doorbell.
    [Master.brd, Master.sch]
2016-03-12 Update Master PCB with correct cutout method.
    OSH Park recommends this method to ensure the cutout is done.
    Added pin definition in firmware for the doorbell input to match PCB.
    [Master.brd]
2016-03-25 Additional notes for MIDI compatibility & plans.
    Added the manual for the Monoprice keyboard, as well as some notes
    on MIDI commands/messages, and some testing on the slave board.
2016-04-08 Move LCD DC Pin to a physical CS pin on the Teensy.
    I failed to notice the library won't support the display if both
    CS and DC pins aren't on hardware CS pins. D'oh!
    [Master.brd, Master.sch]
2016-04-09 Initial I2C address auto-assignment on startup!
    Still a bit rough, and I need to finish up the startup process.
    It needs to kick on the power supply, and let the slaves measure
    their voltages.
2016-04-09 Fix checkboxes in µGUI somewhat.
    Added a couple test options to the settings screen.
    I really need to map out what I want for options, and rewrite the
    whole settings screen.
    [Master.ino, ugui.h]
2016-04-09 Make drawing the BSOD 40% faster.
    Dropped draw time for BSOD from 231 ms to 131 ms by switching to
    drawFastHLine.
    Since the SPI transaction time still is a significant part of the
    wait, I suspect I could make things even faster by updating the
    library to allow pushing a buffer straight to the display, but I
    don't think that is worth it. This is fast enough, IMO.
2016-04-09 Fix BSOD bitmaps.
    They were missing the last run due to a bug in the program I wrote
    to convert them. This happened to work out fine, but doesn't if I
    decompress them to an array and send the array as one operation.
    [Master.ino]
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2016-04-23 Fix overflow causing a missed strike request.
    It was possible that if a strike command was recieved 49.7 days
    (specifically, 4294967295 to 4294967455 ms) after the last strike
    was completed on that channel, the new strike command would be
    ignored.
    This is now fixed.
    [Slave.ino]
2016-04-23 Slave tracks power supply state (BROKEN!).
    This has some form of unexpected behavior where as soon as it starts
    stabilizing, when ps_state_update() is called, it marks it as disabled
    even though it has only been a few microseconds.
    Console output:
    Power supply stabilizing...
    Power supply appears disabled.
    It has been 13 us, and ps_stable_timer > ps_toggle time = 0.
    Power supply stabilizing...
    Power supply appears disabled.
    It has been 15 us, and ps_stable_timer > ps_toggle time = 0.
    Power supply stabilizing...
    Power supply appears disabled.
    It has been 13 us, and ps_stable_timer > ps_toggle time = 0.
    Power supply stabilizing...
    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
    [Slave.ino]
2016-04-23 Temporary fix until I investigate the real cause.
    It appears that some combination of interrupts is causing micros()
    to go backwards in time, leading to garbage data & conclusions.
    [Slave.ino]
2016-04-23 Switched timeout from microseconds to milliseconds.
    This avoids the problem of micros() going backwards, but I would
    still like to get to the bottom of that one at some point.
    [Slave.ino]
2016-04-23 Only diagnose channels when power supply is stable.
    This will prevent false-failing a channel that is being used while
    the power supply stabilizes.
    [Slave.ino]
2016-04-26 Implement Power-On-Self-Test (POST).
    Not completely working on the master yet, but the slave code seems
    solid.
    This version will bug out at runtime if compiled with optimizations!
    The non-optimized (standard) version works fine. I need to figure
    out why, since I might be invoking undefined behavor! Or a GCC bug?
    [Master.ino, Slave.ino, config_file.h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]
2016-04-30 Update settings with physical connections.
    This is how I believe the chimes are going to be hung from the frame.
2016-04-30 Fix master volume not working.
    Also cleanup some coding conventions and remove some commented out code.
    [Master.ino, Slave.ino]
2016-04-30 Initial doorbell support!
    For now, just plays a hard-coded song. Once MIDI file playback is
    working, it will be switched over to play a MIDI file off the SD card.
2016-04-30 Slave firmware is feature-complete!
    This should be stable enough for an initial release.
    Note: the reason the allowed error is so hihg (20%) is because one
    of my coils appears to have some damage (internal shorts) and is
    ~15% out from the rest. So for now, I just allow it, but I might
    repair/replace the damaged coil and tighten up the allowed error.
    The rest of the coils are within 1% of expected from what I see.
    [Slave.ino]
2016-05-01 Adjust error limits on coils.
    Turns out I had a completely toast coil that was drawing > 10A,
    which exceeds the ratings of the transistors. Using the original
    limit will protect the slave boards. I will just have to replace
    the coil.
    [Slave.ino]
2016-05-01 Make slaves 1-indexed & work around Teensy/GCC bug.
    Slaves are now numbered starting from 1 in the Settings.ini file and in
    all program outputs. This is now consistent with how channels are
    presented, and is more intuitive for "normal" people.
    There is a bug where malloc() and new both fail spectacularly with the
    Teensy's version of GCC. This is visible when attempting to malloc()
    more RAM than is available. Instead of returning a null pointer (per the
    spec), it just hangs.
    Dealing with dynamically sized arrays of classes appears to invoke the
    same behavior, leading to seemingly random and implausible crashes &
    bugs. But now that I am sticking with a single static instance of the
    class, al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
    [Master.ino, slave_status.cpp, slave_status.h]
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2016-05-01 Periodically check slaves for malfunctions.
    This lets us report the failure, instead of blissfylly carrying on after
    a slave has disabled the power supply, or at least started ignoring
    commands to a damaged channel.
    [Master.ino]
2016-05-01 Additional diagnostic tools for slaves.
    You can now force a failure on Channel 1 for the slave for testing.
    [Slave.ino]
2016-05-01 Change the order of the slave diagnostics.
    This results in a more detailed error message if the failed channel is
    mapped to a note.
    [Master.ino]
2016-05-02 Allow increased error when striking multiple chimes.
    This compensates for power supply droop and voltage drop across the
    slave PCB traces under high-load situations.
    [Slave.ino]
2016-05-02 Implement Master Volume support & fix lots of bugs.
    Calibration now works right, fixes hang on I2C bus errors, etc.
    [Master.ino]
2016-05-04 Add mount for Master PCB.
    Also add the datasheet for the MIDI Jack that was used when creating the mount.
    [Master Board Mount.FCStd, Master Board Mount.stl]
2016-05-04 Fix Master PCB mount.
    I had failed to mirror-image the standoffs, since the board mounts
    upside down compared to the model. D'oh!
    [Master Board Mount.FCStd, Master Board Mount.stl]
2016-05-05 Improve master mount.
    Add additional supports to strengthen the mounts. They proved fragile
    once printed.
    Also fixed the alignment of one of the mounts. I dimensioned to the
    wrong edge, ending with the mount off 0.1".
    [Master Board Mount with Pilot Holes.stl, Master Board Mount.FCStd, Master Board Mount.stl]
2016-05-05 Add clip mounts for Slave PCBs.
    Each slave uses 2 of these clips, rotated 180° from each other.
    [Slave Board Clip.FCStd, Slave Board Clip.stl]
2016-05-07 Add additional debug output to Slave.
    This appears to have solved a problem where a slave wouldn't fail
    an open-circuit channel, but with the debug code merely present,
    suddenly it catches the error.
    So there is probably some undefined behavior in my code that I need
    to find and fix. I suspect num_striking().
    [Slave.ino]
2016-11-18 Limit simultaneous chime strikes.
    This prevents overloading the power supply.
    [Master.ino]
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2016-11-20 Fix backlight dimming on capacitive TS.
    Adafruit's schematic (or my understanding of it?) was wrong, and the
    capacitive touchscreen uses digital pin 5 for backlight dimming, not
    digital pin 3.
    Since most pins are unused, just hooking pins 3 and 5 together works
    fine, and requires no other changes. Now the PCB supports either TS.
    [Master.brd, Master.sch]
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
